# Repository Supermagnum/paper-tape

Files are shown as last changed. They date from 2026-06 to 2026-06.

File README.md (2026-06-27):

# Paper Tape Reader

**Repository:** [github.com/Supermagnum/paper-tape](https://github.com/Supermagnum/paper-tape)

<a href="https://www.pcbway.com/project/shareproject/paper_tape_reade_0e895082.html">PCB from PCBWay</a>

Design and documentation by [Jürgen Müller / e-basteln](https://e-basteln.de/computing/papertape/overview/). This repository contains the firmware, PCB design files, and manufacturing data for the manual optical paper tape reader described on the [e-basteln Paper Tape Reader pages](https://e-basteln.de/computing/papertape/overview/).

PCB files converted to KiCad. Note that the main board and included template PCBs use **1.6 mm** thickness. The Gerber files in `gerbers/papertape_spacer/` are for the **1.6 mm templates** (identifiable by their larger aperture holes), used as alignment guides during assembly.

The actual **spacers** (2× 1.2 mm thick) are **not included as Gerber files** and must be made separately. The main board and spacer templates also require **different PCB thicknesses** and must be ordered as **separate jobs** from your PCB manufacturer. Both 1.6 mm and 1.2 mm are standard thickness options at JLCPCB and PCBWay, with a minimum order of 5 pieces each.

The material of the spacers is not important, they just have to be light-tight. Options include 3D printing in black filament, or cutting from 1.2 mm black acrylic or similar opaque material. Use the 1.6 mm template PCB as a guide when making them. Make 2× spacers, for a total thickness of 2.4 mm.

## Table of Contents

- [Overview](#overview)
- [Using the Reader](#using-the-reader)
  - [Capturing tape data](#capturing-tape-data)
  - [After capture](#after-capture)
  - [Archiving captures on Codeberg](#archiving-captures-on-codeberg)
    - [Creating a Codeberg account](#creating-a-codeberg-account)
    - [Creating a repository](#creating-a-repository)
    - [Uploading files via the web interface](#uploading-files-via-the-web-interface)
- [LEDs](#leds)
- [Calibration](#calibration)
- [Jumpers](#jumpers)
- [Serial Output](#serial-output)
- [Building the Reader](#building-the-reader)
  - [Builder's Hints](#builders-hints)
    - [Sourcing the parts](#sourcing-the-parts)
    - [Preparing the PCBs](#preparing-the-pcbs)
    - [Populating components](#populating-components)
    - [Populating sockets and pins](#populating-sockets-and-pins)
    - [Programming the Pro Micro](#programming-the-pro-micro)
- [Design Approach](#design-approach)
- [The Sales Pitch](#the-sales-pitch)
- [Where to Find Files](#where-to-find-files)
- [Design Files](#design-files)
  - [Changes in this repository](#changes-in-this-repository)

## Overview

This little manual paper tape reader is easy to build and operate. It connects to any modern computer via USB, and performs well with all kinds of 5 to 8 bit paper tape, including translucent paper materials. To compensate for sensor tolerances and adjust to different paper types, it can automatically calibrate its optical sensors.

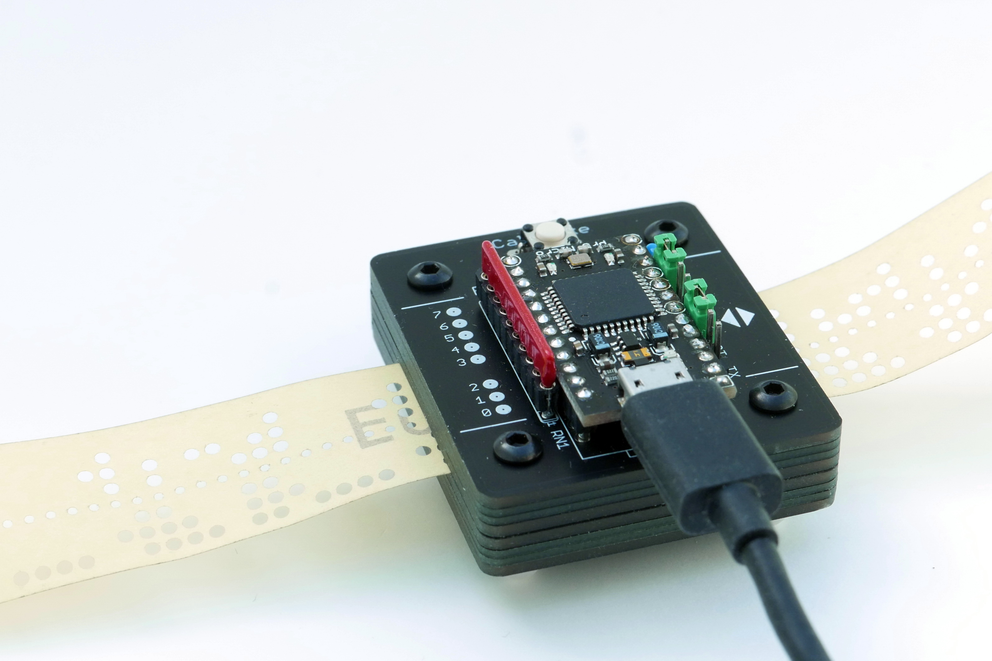
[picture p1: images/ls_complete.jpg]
Paper tape reader, fully assembled


The paper tape reader is controlled by an Arduino Pro Micro. Punched holes are detected optically, via analog inputs to the Arduino and automatic thresholding in software.

Optical readers for punched paper tape have been used since the 1940s; the one developed in 1942 for the British Heath Robinson deciphering machine was probably among the earliest. Non-motorized optical readers, where the tape is pulled through by hand, became popular with early computer amateurs in the 1970s. Oliver Audio Engineering launched the OP80A as a kit or complete unit in 1976; a replica is still commercially available today. And to this day, amateurs interested in the old paper tape format occasionally build their own optical readers.

Operate the reader handheld or mounted to a base plate. Tape is pulled through manually, at up to 1 meter/second feed rate.

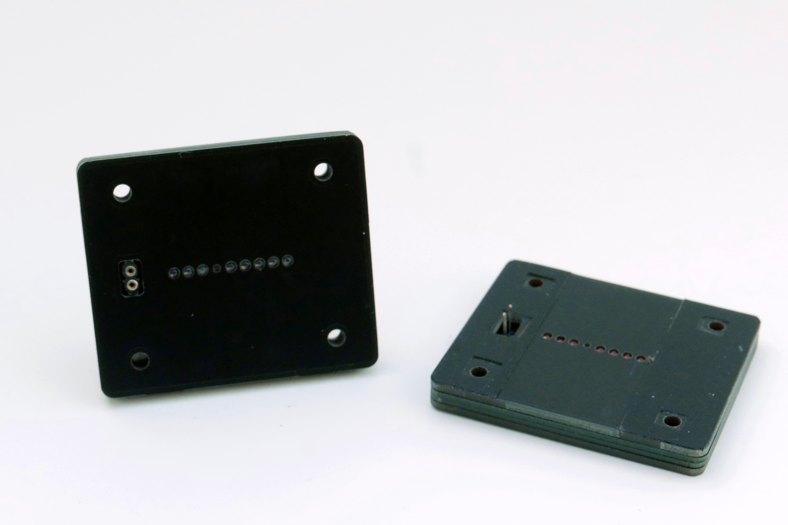
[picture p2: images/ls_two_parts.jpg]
Paper tape reader, illumination and detection module


The two main modules are the phototransistor detector (left) and the LED illuminator (right). The Arduino sits on top of the detector module. Only two power connections go to the illuminator.

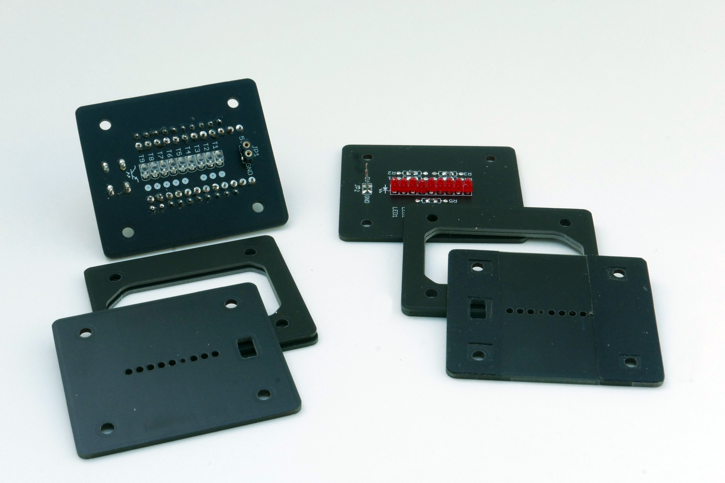
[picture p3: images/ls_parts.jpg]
Paper tape reader, individual parts


All chassis parts are made from PCB material: Circuit boards for phototransistors and LEDs, masks to precisely define the illumination and detection apertures, and light-tight spacers.

## Using the Reader

To use the paper tape reader, simply connect it to a Windows 10, Linux or Mac OS computer via USB. The reader should automatically register as a USB CDC device (communication device class, a virtual serial port).

Start a terminal program of your choice and select the right (virtual) serial port. No need to set the baud rate etc., since no physical serial port is involved. The reader will start sending data as soon as you pull paper tape through.

Before the first operation, or when switching to a new type of paper tape with very different transparency, calibrate the reader as described below.

### Capturing tape data

Open the serial port and save the received contents to a `.txt` file with **no processing**. Capture the raw bytes exactly as received, save as plain text, and do not strip or convert anything. This means:

- No parity bit masking
- No line ending conversion
- No stripping of leader/trailer nulls
- No interpretation of control characters

This preserves everything and keeps your options open for later analysis.

**Linux:** find the device (often `/dev/ttyACM0` or `/dev/ttyUSB0`), then capture directly:

```bash
stty -F /dev/ttyACM0 raw -echo
cat /dev/ttyACM0 > 20250627_tape_001.txt
```

Press Ctrl+C when the tape has passed through. Do not pipe through tools that alter line endings or encoding.

**macOS:** same approach using the device under `/dev/tty.usb*` or `/dev/cu.usb*`.

**Windows:** use a terminal that can log raw serial data to a file without translation (for example PuTTY with "All session output" logging, or a dedicated serial capture tool). Disable any "local echo", line editing, or automatic CR/LF conversion in the terminal settings.

A good naming convention helps since you do not know the content yet:

```
YYYYMMDD_tape_001.txt
```

If you are digitizing a collection, this lets you track what you have read and when, and rename files later once you figure out what each tape contains.

### After capture

Once you have a faithful raw capture, you can:

- Open it in a hex editor to inspect the raw bytes and identify the format
- Run `file tape_001.txt` on Linux, which will attempt to auto-detect the content type
- Look for recognizable patterns such as keywords (`PROGRAM`, `BEGIN`, `MOV`, `LDA`, etc.) that identify the language
- Check the [bitsavers.org](https://bitsavers.org/) archive, which has a large collection of documented paper tape formats for comparison

The key principle is: **capture first, identify later**. You can always convert a faithful raw capture, but you cannot recover data that was thrown away during capture.

### Archiving captures on Codeberg

If you want to share digitized tapes with the retrocomputing community, [Codeberg](https://codeberg.org/) is a good place to host them. Codeberg is independently operated by [Codeberg e.V.](https://codeberg.org/Codeberg/Association), a non-profit association registered in Berlin, Germany. It is community driven, privacy focused, and runs on the open-source [Forgejo](https://forgejo.org/) platform under German and EU law (GDPR). For archival work, that means no commercial pressure to monetize the platform, stronger data protection than many US-hosted services, and a community that tends to appreciate preservation projects.

#### Creating a Codeberg account

1. Open [codeberg.org](https://codeberg.org/) in your browser.
2. Click **Register** in the top-right corner.
3. Choose a username, enter your email address, and set a password.
4. Complete the registration form and submit it.
5. Check your email for a confirmation link from Codeberg and click it to activate the account.
6. Sign in with your new username and password.

#### Creating a repository

1. After signing in, click the **+** icon in the top-right corner and select **New Repository**.
   Alternatively, open your dashboard and click **New Repository** there.
2. Fill in the repository details:
   - **Owner:** your username (or an organization, if you belong to one)
   - **Repository name:** for example `paper-tape-archive`
   - **Description:** short summary, e.g. "Digitized paper tape captures"
   - **Visibility:** choose **Public** if you want others to browse and clone the archive
   - **Initialize repository:** leave **Add a README file** unchecked if you plan to upload your own files immediately; check it if you want Codeberg to create an empty starter `README.md` for you
3. Click **Create Repository**.

You now have an empty repository ready for uploads.

#### Uploading files via the web interface

Codeberg's web interface lets you add files without installing Git on your computer. This works well for small archives and individual tape captures.

**Upload the first files to an empty repository:**

1. Open your new repository in the browser.
2. If the repository is completely empty, Codeberg shows an **Upload file** option on the landing page. Click it.
   If the repository already has files, go to the **Code** tab, click the **+** drop-down next to the path bar, and choose **Upload file**.
3. Drag and drop files into the upload area, or click to browse your computer.
4. In the **Commit message** field, enter a short note such as `Add initial archive structure`.
5. Optionally expand **Commit options** and choose whether to commit directly to the default branch (usually `main`).
6. Click **Commit changes**.

**Add a tape capture in a subdirectory:**

1. Navigate to the folder where the tape should live, for example `tapes/unknown/20250627_tape_001/`.
   To create a new folder path, type the full path into the filename field when uploading, for example:
   `tapes/unknown/20250627_tape_001/tape_001.txt`
   Codeberg creates any missing directories automatically.
2. Upload the raw capture file (`tape_001.txt`) and the tape's `README.md` (create the README in the web editor if you prefer).
3. Enter a commit message such as `Add tape 001 capture from 2025-06-27`.
4. Click **Commit changes**.

**Create or edit a README in the browser:**

1. On the **Code** tab, click the **+** drop-down and choose **New file**.
2. Enter the path, for example `tapes/unknown/20250627_tape_001/README.md`.
3. Type or paste the README content into the editor.
4. Add a commit message and click **Commit changes**.

Repeat for each new tape. Once you have several captures, consider organizing them using the directory structure below.

Suggested directory structure:

```
paper-tape-archive/
├── README.md                    # Project description, how to contribute
├── FORMATS.md                   # Notes on identified tape formats
│
└── tapes/
    ├── unknown/                 # Tapes not yet identified
    │   └── 19700101_tape_001/
    │       ├── README.md        # Date, physical condition, likely source
    │       ├── tape_001.txt     # Raw capture
    │       └── tape_001.bin     # Raw binary if needed
    │
    ├── assembler/
    │   └── 19780315_tape_002/
    │       ├── README.md
    │       └── tape_002.txt
    │
    ├── basic/
    ├── fortran/
    ├── pascal/
    └── other/
```

Each tape's `README.md` should contain something like:

```markdown
# Tape 001

- **Date captured:** 2025-06-27
- **Capture device:** Paper Tape Reader (github.com/Supermagnum/paper-tape)
- **Likely source:** [e.g. university surplus, estate sale, donated collection]
- **Physical condition:** [good/fair/poor, any damage notes]
- **Tape width:** [5/7/8 bit]
- **Identified format:** unknown
- **Notes:** [anything else relevant]
```

Move tapes from `unknown/` into `assembler/`, `basic/`, `fortran/`, or another category once the format is identified, and update `FORMATS.md` with what you learned.

## LEDs

Two LEDs on the Pro Micro board are used to signal the operating status. They are labelled on the detector PCB:

- **FEED** flashes once for every valid feed hole detected during operation and calibration.
- **CAL** indicates that calibration mode is active, or that a calibration is recommended.

| CAL indication | Meaning |
|---|---|
| Steady ON | Calibration mode is active |
| Flashing, 1 Hz | Waiting for user to start calibration (press CAL button), or for 10 s timeout |
| Flashing, 10 Hz | Error during the calibration process |
| ON in read mode | Invalid brightness levels have been read (no clear high or low). Recalibration is recommended. |

## Calibration

1. Press **CAL** once to view the current calibration. Current calibration values are printed via USB, the CAL LED blinks at 1 Hz.
2. Press **CAL** again within 10 seconds to enter calibration mode. You will be prompted via a USB message to start feeding tape, the CAL LED turns on.
3. Feed tape, beginning within 10 seconds. Approximately 30 cm of sample tape are required. Ideally all data bits should be exercised in the sample, but if no significant contrast is detected for a data channel, averaged thresholds from the other channels will be used. The CAL LED stays on, the FEED LED begins to flash when valid feed holes are seen.
4. Calibration automatically ends when enough sample tape has been processed, or when one of the 10 second timeouts mentioned above is reached. Results and final status are printed via USB; errors are also signaled by rapid flashing of the CAL LED for 1 second. The CAL LED is then switched off.

## Jumpers

Three different tape widths can be set via jumpers. Setting them properly is recommended to avoid "CAL" indications from invalid detection levels at the tape edges, and to mask invalid bits from the output bytes.

| Tape width | Tape/bit placement | Jumper settings |
|---|---|---|
| 8 bit | 76543.210 | 5BIT=open, TST=open |
| 7 bit | - 6543.210 | 5BIT=set, TST=set |
| 5 bit | - - 432.10 - | 5BIT=set, TST=open |

Note that the 7-bit setting is only required for the rather uncommon type of paper tape which is physically only seven rows wide. For this narrower tape, the 7-bit setting masks out any invalid readings from the eighth detector (which looks just at the tape edge). The common 1" wide tape can be read in the 8-bit setting, no matter whether seven or eight rows of holes are actually punched on it.

Setting only the **TST** jumper will activate test mode, where the raw ADC readings from all 9 channels are printed on the output in an endless loop. From left to right, bits 0 to 7 are displayed, followed by the feedhole signal on the far right. A high value, up to 255, indicates high brightness.

The **INV** jumper will set the reader to use inverted intensity thresholds, i.e. a logical '1' or an active feed track pulse are signaled by a dark light level. This is useful for reading paper tapes which have not been punched, but printed on thin paper, for demonstrations or tests where real paper tape and a punch device are not available. Since the light levels will be lower in this case, it is recommended to replace the resistor array RN1 by a 22 kOhm array.

**TX** is not a jumper, but a serial output. This can optionally be used to connect legacy equipment. Please see the Serial Output section below for details.

## Serial Output

Normally, the USB port is used to interface the tape reader to a modern computer. If you want to read paper tapes into a vintage computer without a USB port, you can use the TX pin on the jumper row which sends "real" serial data.

- All data read from paper tape will be transmitted as an asynchronous serial data stream: 9600 baud, 8 data bits, no parity, 1 stop bit. Voltage levels are positive: A logical '1' (which is also present at rest) is represented by +5 V, a logical '0' (which is also the start bit of each character) by 0 V.
- The baud rate can only be changed by editing the Arduino source code. Look for the `SERIAL_INIT()` call; this is a macro which goes back to `Serial1.begin()` and accepts the baud rate as a parameter.
- To connect to computers with classic RS-232 ports, an external level converter to +/-5 V .. +/-12 V is needed. These are available off-the-shelf or as a kit. They also invert the signal polarity, making logical '1' a negative voltage as defined in the RS-232 standard.
- To provide 5 V power to the level converter, you can omit capacitor C1 and install two more posts (pins) in that position. The outermost pin has +5 V, the next one is another GND pin (see the pin table below). You can also power the paper tape reader via this pin if you do not want to use the USB port.
- Neither calibration data and prompts nor the raw ADC readings in TST mode will be transmitted via this output. This is deliberate; the idea is to use a modern PC to set up the reader, and not bother the vintage system with these setup data.

Summary of all pins on the jumper row and their functions:

| Pin | Function |
|-----|---|
| +5 V | Power, e.g. for optional external RS-232 level converter |
| GND | Ground (0 V) |
| 5BIT | Jumper to GND: 5 bit or 7 bit tape width |
| GND | Ground (0 V) |
| INV | Jumper to GND: Use printed paper tape with dark 'holes' |
| GND | Ground (0 V) |
| TST | Jumper to GND: Test mode, transmit raw ADC readings via USB |
| GND | Ground (0 V) |
| TX | Serial output: TTL level, 9600 8N1 |
| GND | Ground (0 V) |

## Building the Reader

There are no step-by-step illustrated building instructions here. But with the sectional view of the PCB stack below and the following hints the build should be straightforward.

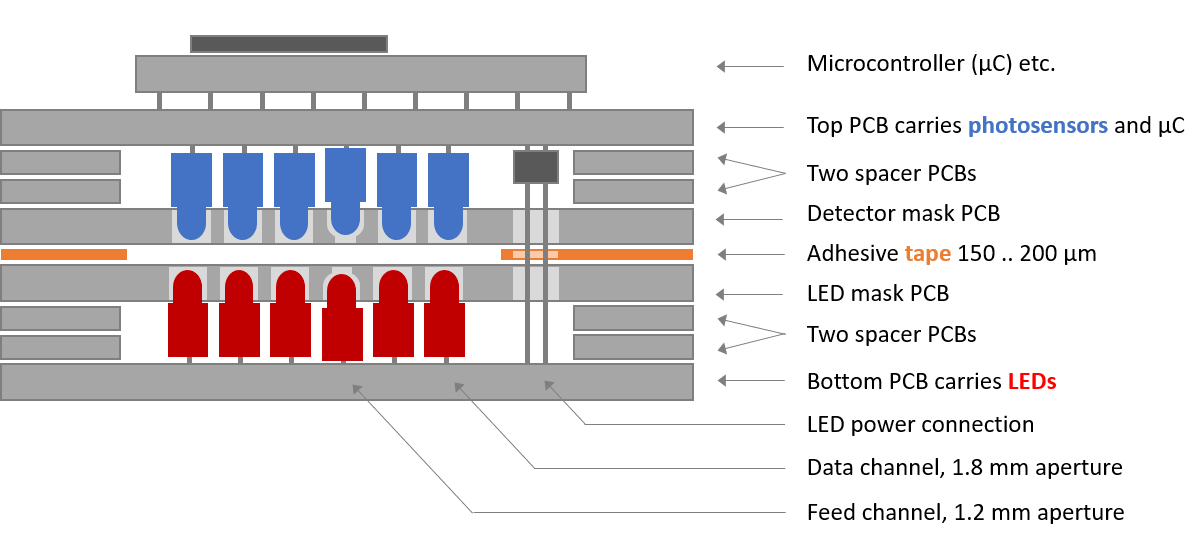
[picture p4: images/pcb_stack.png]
Sectional view of PCB stack and key components


Sectional view of the stack of PCBs which make the chassis, as well as the key electronic components. For clarity, only 5 of the 8 data sensors and LEDs are shown.

### Builder's Hints

#### Sourcing the parts

- The design files for the custom circuit boards are provided in the Design Files section below. You can order the PCBs cheaply from vendors like JLCPCB, PCBWay, Aisler etc. by uploading the zipped Gerber files provided.
- The [PCBWay shared project](https://www.pcbway.com/project/shareproject/paper_tape_reade_0e895082.html) lists all parts needed to build the reader (PCBs and components). The part list is in `docs/papertape_bom_PCBWay Community.csv`.
- While the microcontroller board is commonly called an "Arduino Pro Micro", and is fully compatible with the Arduino development tools, it was not designed by the Arduino company but by Sparkfun. You can purchase the original Sparkfun Pro Micro or one of various cheaper "Pro Micro" or "Arduino Pro Micro" clones available on ebay etc. In either case, be sure to buy the **5 V / 16 MHz** version! The variant operating at 3.3 V and 8 MHz is not suitable for this project.
- A Digikey shopping cart is available for most of the other parts. If you are based in Europe, Reichelt may be a lower-cost alternative supplier (see the bill of materials in the Design Files section below). The Digikey cart contains alternative values for the resistor array (2.7 kOhm or 10 kOhm), in case of major batch variations of the LEDs or photo-transistors. These may not be necessary. To my knowledge, all builds so far have successfully used the standard 4.7 kOhm array.

#### Preparing the PCBs

- The circuit boards and aperture boards for the detector and illumination are all made in one piece, to ensure that holes and milling contours align on all of them. (Probably an unnecessary precaution.) Hence you need to first break these boards apart, roughly clip off the tabs, and then sand the contours smooth. I recommend that you assemble the complete PCB package with screws according to the picture below and then sand it as a package to obtain even contours.
- Please note that the fibers in PCB dust may be harmful. Work outside or in an area where you can contain the dust, and wear a protective mask.

*The stack of PCBs that make the paper tape reader.*

- The aperture hole for the feed track is only 1.2 mm in diameter, matching the feed holes in the paper tape for maximum signal modulation. On both aperture PCBs this hole needs to be drilled out to 1.8 mm to accommodate the LED and phototransistor, as indicated in the silk screen print on the PCB. But do not drill all the way through; this must be drilled as a blind hole, preserving the 1.2 mm optical aperture! Note that extreme care must be exercised in drilling this hole. Use a drill press and/or much care to drill to the right depth. The standard tolerance for a 1.6 mm PCB is ±10%, which means ±0.16 mm. The WP406A10SURDK LED protrudes 1.55 mm up from its body; tolerance is ±0.25 mm, so start with a hole depth of 0.5 mm. Maximum you'd ever need to drill is 1.0 mm, leaving at worst 0.44 mm of wall.

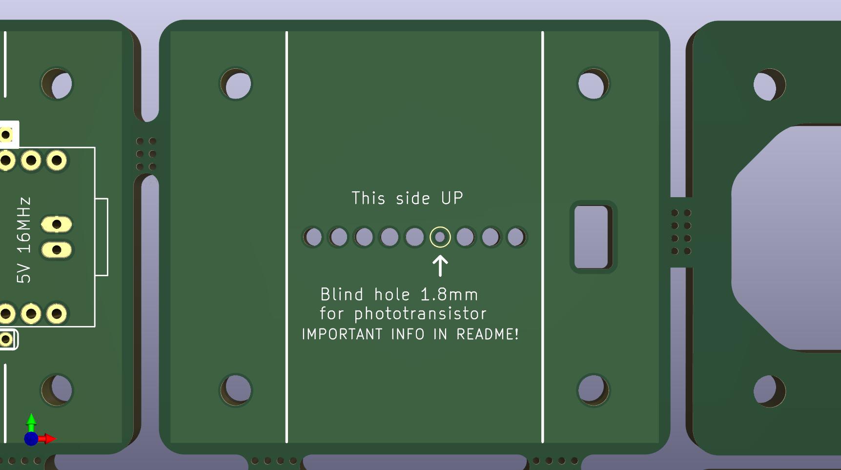
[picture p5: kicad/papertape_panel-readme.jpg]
Feed-track blind-hole drilling on aperture PCB


- To create a gap for the paper tape between the two aperture PCBs, two strips of adhesive tape are placed on top of the LED aperture board. This also provides lateral guidance for the paper tape, so you have to decide on a tape width you want to read. (I intend to provide inserts to reduce from 8-bit tape to 7 or 5 bit width, but have not tried this yet.)
- Fix the aperture PCB to the work bench with a bit of adhesive tape, position a short piece of punched paper tape exactly over the apertures as a reference and attach it to the bench as well. Apply two strips of adhesive tape to the PCB, right next to the paper tape, as a spacer and guide. About 200 um should be a good thickness; you may need to stack two layers of electrical tape or similar to get there. With a sharp knife, trim the tape along the PCB contours and cut the holes for screws and power connector.
- To make it easier to introduce the paper tape into the narrow gap later, you can lightly sand the edges of the LED aperture PCB in the space between the two guide tapes. This creates a slight "funnel" for insertion of the paper tape.

*The pre-assembled modules: Phototransistor detector with apertures (left) and LED illuminator with apertures and spacer tape (right). Two sockets and wires provide power to the LEDs.*

#### Populating components

- To populate the LEDs, insert all 9 loosely into the PCB. (Note the correct orientation; the body outline is shown on the silkscreen print.) Put the two spacer PCBs and the aperture PCB on top, wiggle the LEDs into their respective aperture holes, and hold the PCB stack together with screws or adhesive tape. Push the LEDs all the way down into their holes. The feed hole LED will not go quite as far into its blind hole as the other LEDs. Then solder all LEDs.
- Do the same with the phototransistors.
- The LED series resistors (R1 to R5) can be populated as through-hole resistors inside the module. This requires resistors with a diameter less than 2.4 mm, the thickness of the two spacer PCBs. The diameters of through-hole resistors vary by manufacturer. If you cannot find suitably slim through-hole resistors, you can either mount them on the opposite side of the PCB, or you can populate 0603 or 0805 sized SMD resistors on the provided pads.

#### Populating sockets and pins

- For the 5V power connection to the illuminator module, solder a two pin socket to the bottom of the detector board. (Make sure to get it reasonably straight.) Insert two clipped wire ends into the sockets. Provisionally assemble the full PCB stack while guiding the wires through their pads in the illuminator board. Clip wires to length and solder them to the illuminator board.
- You can solder the Arduino Pro Micro permanently to the detector PCB with the square soldering pins provided with most Arduino boards. This will give the lowest-profile package. If that is what you prefer, make sure that the phototransistors and 5V supply socket are soldered before you place the Arduino! Alternatively, use two rows of 1x12 pin sockets for the Arduino. In that case, the standard square pins will not fit, and you need to obtain smaller (turned) pin headers to match the sockets.
- The resistor array RN1 (9 x 4.7 kOhm) can be soldered directly if you only want to read "real", punched paper tape. Be sure to check the orientation; the common pin must be oriented towards the USB jack. If you want to use printed tape in the future, i.e. black dots on translucent paper, you may need to exchange RN1 for a 22 kOhm or 33 kOhm array to give higher light sensitivity. In that case, use a 1x10 pin socket for RN1.

*I opted for sockets for the resistor array (so I can try different values) and the Arduino (in case I need to get to the soldering joints beneath it).*

#### Programming the Pro Micro

- The Pro Micro processor is programmed via the regular Arduino environment, via its Micro USB connection. Please find the source code for the paper tape reader in the Design Files section just below.
- The Pro Micro board description is not pre-installed in the Arduino IDE. The required steps are briefly presented below. There is also a more detailed tutorial from Sparkfun; see the "Installing on Windows" or "Installing on Mac/Linux" sections there. That tutorial also covers manual installation of the serial driver on Windows if it is not available automatically (as it should from Windows 10 onwards).
- First, select **File / Preferences** from the main menu. In the dialog which opens, enter the URL below in the "Additional Board Manager URLs" field. Then select **Tools / Board / Boards Manager** and install the "SparkFun AVR Boards" package.

  ```
  https://raw.githubusercontent.com/sparkfun/Arduino_Boards/master/IDE_Board_Manager/package_sparkfun_index.json
  ```

- Again from the main menu, select **Tools / Processor: ATmega32U4 (5V, 16 MHz)**. It is important to choose the right version! If you accidentally try to program a 5V Pro Micro with the settings for the 3.3V version, you may brick it, requiring a hard reset. Connect the Pro Micro via USB, and set the right COM port via **Tools / Port**. Now you are ready to compile and upload the paper tape reader's software!

## Design Approach

This project takes a slightly different approach than most builds. While I also use LED and phototransistor pairs to detect the presence of holes or paper, and use the feed (sprocket) hole to trigger a read cycle, this reader does not distinguish "zero" from "one" via hardware comparators or Schmitt triggers. Instead, the on-board microcontroller (a Sparkfun/Arduino Pro Micro) reads the phototransistor currents via its analog inputs. This way it can adjust the detection thresholds in software, to compensate for tolerances between the phototransistors and to adjust to different paper materials.

## The Sales Pitch

- **Easy to use.** Just connect it to any modern computer (Windows 10, Mac OS, Linux) via USB, open a terminal program or copy from the serial device to a file, pull through some paper tape, and you are in business. You can calibrate the sensors to difficult-to-read, translucent tape by pushing a button and feeding about 30 cm of test tape. But one calibration handles a wide range of paper types, and stays resident in EEPROM memory, so you do not have to calibrate much at all.
- **Easy to build.** Only through-hole electronic components are required. Most mechanical parts consist of pre-fabricated circuit board material; just add four screws and some adhesive tape (which is used as a spacer to guide the paper tape). No hand-selected resistor values to get the sensor switching thresholds just right, since all sensors are calibrated in software. The microcontroller is programmed via USB and the standard Arduino environment.
- **Works pretty well.** Due to the analog sensing and software calibration, the reader handles a wide variety of tape materials robustly, including highly translucent white or yellow paper. It is insensitive to environmental light since the tape and sensors are fully encapsulated. While it is not the fastest reader around, reading speed is probably limited by how fast you can pull the tape through without damaging it: Reading at 1.2 meter/second (500 characters per second) should not be a problem.

## Where to Find Files

Clone or download this repository from [github.com/Supermagnum/paper-tape](https://github.com/Supermagnum/paper-tape).

```
paper-tape/
├── README.md                      # This manual
├── Paper_Tape_Reader.ino          # Arduino firmware
├── papertape_pcb.sch              # Original Eagle schematic
├── papertape_pcb.brd              # Original Eagle main PCB
├── papertape_spacer.brd           # Original Eagle spacer PCB
├── kicad/
│   ├── papertape_pcb.kicad_pcb    # Main PCB (KiCad, converted from Eagle)
│   ├── papertape_pcb.kicad_sch    # KiCad schematic
│   ├── papertape_pcb.kicad_pro    # KiCad project file
│   ├── papertape_spacer.kicad_pcb # Spacer PCB (KiCad)
│   └── papertape_panel.kicad_pcb  # Panel: main + 4x spacer (2x2, 2 mm gap)
├── gerbers/
│   ├── papertape_pcb/             # Gerbers for main board
│   ├── papertape_spacer/          # Gerbers for spacer board
│   └── papertape_panel/           # Gerbers for combined panel
├── docs/
│   ├── papertape_bom.pdf          # Bill of materials (original)
│   ├── papertape_bom.csv          # Bill of materials with manufacturer MPNs
│   ├── papertape_bom_PCBWay Community.csv  # Part list for PCBWay shared project
│   ├── papertape_all.pdf          # Full design documentation (PDF)
│   └── Paper_Tape_Template.xlsx   # Paper tape template
└── images/                        # Build photos and PCB stack diagram
    ├── ls_complete.jpg
    ├── ls_two_parts.jpg
    ├── ls_parts.jpg
    └── pcb_stack.png
```

Order PCBs and components from the [PCBWay shared project](https://www.pcbway.com/project/shareproject/paper_tape_reade_0e895082.html), which includes all parts needed; see `docs/papertape_bom_PCBWay Community.csv` for the part list. Alternatively, upload the Gerber files from `gerbers/papertape_pcb/` and `gerbers/papertape_spacer/`, or use `gerbers/papertape_panel/` for the combined panel layout. Both PCBWay and JLCPCB have a minimum order of 5 sets.

## Design Files

| File / directory | Description |
|---|---|
| `Paper_Tape_Reader.ino` | Arduino firmware source code |
| `kicad/papertape_pcb.kicad_pcb` | Main detector/illuminator PCB (KiCad) |
| `kicad/papertape_spacer.kicad_pcb` | Spacer PCB (KiCad) |
| `kicad/papertape_panel.kicad_pcb` | Combined panel: main board + 4x spacer (2x2 grid, 2 mm routing gap) |
| `kicad/papertape_pcb.kicad_sch` | KiCad schematic |
| `gerbers/papertape_pcb/` | Gerber + drill files for main board |
| `gerbers/papertape_spacer/` | Gerber + drill files for spacer |
| `gerbers/papertape_panel/` | Gerber + drill files for panel |
| `docs/papertape_bom.pdf` | Bill of materials (original PDF) |
| `docs/papertape_bom.csv` | Bill of materials with manufacturer part numbers (CSV) |
| `docs/papertape_bom_PCBWay Community.csv` | Part list for the PCBWay shared project (all parts needed) |
| `papertape_pcb.sch`, `papertape_pcb.brd` | Original Eagle design files |
| `papertape_spacer.brd` | Original Eagle spacer board |

### Changes in this repository

The original Eagle designs from [e-basteln](https://e-basteln.de/computing/papertape/overview/) have been converted to KiCad (`papertape_pcb.kicad_pcb`, `papertape_spacer.kicad_pcb`). During conversion, pre-drill holes were added to the PCB files where required for blind-milled feed-track apertures and other mechanical features that are not represented in the standard drill file alone.

For panelised manufacturing, the main PCB and spacer boards are also combined in `kicad/papertape_panel.kicad_pcb`: one main board at its original position, plus four spacer instances in a 2x2 grid to the right with a 2 mm routed gap between boards. Each panel is one complete set; PCBWay and JLCPCB both require a minimum order of 5 sets.

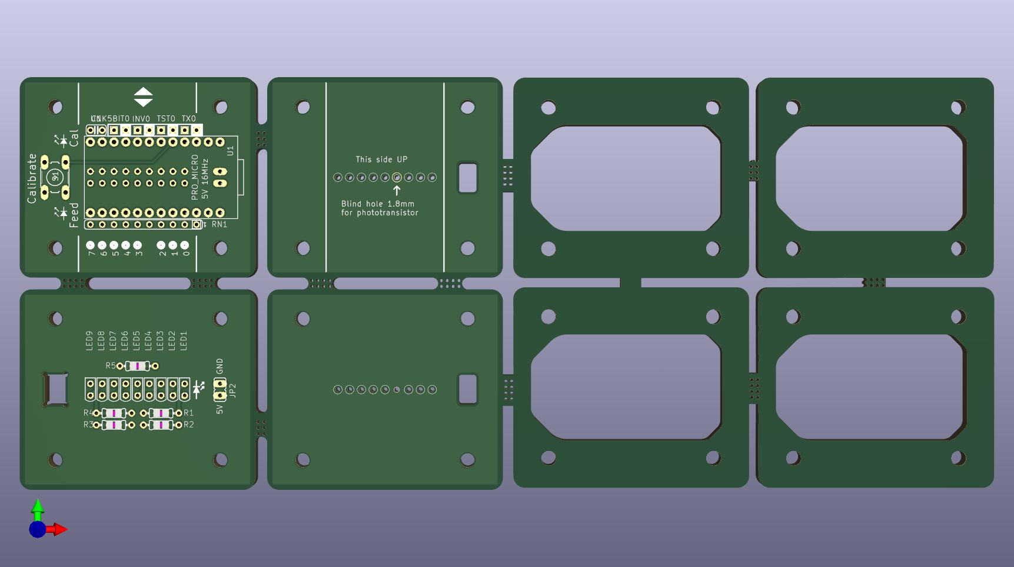
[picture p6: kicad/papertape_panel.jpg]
Paper tape PCB panel layout


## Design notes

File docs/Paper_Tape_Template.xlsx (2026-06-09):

"Punched" Paper Tape Template
jm 25.12.2020
Enter ASCII letters in green cells below
T | e | s | t |  | t | h | e |  | q | u | i | c | k |  | b | r | o | w | n |  | f | o | x |  | j | u | m | p | e | d |  | o | v | e | r |  | t | h | e |  | l | a | z | y |  | d | o | g | . |  | T | E | S | T |  | T | H
l | l | l | l |  | l | l | l |  | l | l | l | l | l |  | l | l | l | l | l |  | l | l | l |  | l | l | l | l | l | l |  | l | l | l | l |  | l | l | l |  | l | l | l | l |  | l | l | l |  |  | l | l | l | l |  | l | l
 | l | l | l | l | l | l | l | l | l | l | l | l | l | l | l | l | l | l | l | l | l | l | l | l | l | l | l | l | l | l | l | l | l | l | l | l | l | l | l | l | l | l | l | l | l | l | l | l | l |  |  |  |  |  | l
l |  | l | l |  | l |  |  |  | l | l |  |  |  |  |  | l |  | l |  |  |  |  | l |  |  | l |  | l |  |  |  |  | l |  | l |  | l |  |  |  |  |  | l | l |  |  |  |  |  |  | l |  | l | l |  | l
 |  |  |  |  |  | l |  |  |  |  | l |  | l |  |  |  | l |  | l |  |  | l | l |  | l |  | l |  |  |  |  | l |  |  |  |  |  | l |  |  | l |  | l | l |  |  | l |  | l |  |  |  |  |  |  |  | l
l | l | l | l | l | l | l | l | l | l | l | l | l | l | l | l | l | l | l | l | l | l | l | l | l | l | l | l | l | l | l | l | l | l | l | l | l | l | l | l | l | l | l | l | l | l | l | l | l | l | l | l | l | l | l | l | l | l
l | l |  | l |  | l |  | l |  |  | l |  |  |  |  |  |  | l | l | l |  | l | l |  |  |  | l | l |  | l | l |  | l | l | l |  |  | l |  | l |  | l |  |  |  |  | l | l | l | l |  | l | l |  | l |  | l
 |  | l |  |  |  |  |  |  |  |  |  | l | l |  | l | l | l | l | l |  | l | l |  |  | l |  |  |  |  |  |  | l | l |  | l |  |  |  |  |  |  |  | l |  |  |  | l | l | l |  |  |  | l
 | l | l |  |  |  |  | l |  | l | l | l | l | l |  |  |  | l | l |  |  |  | l |  |  |  | l | l |  | l |  |  | l |  | l |  |  |  |  | l |  |  | l |  | l |  |  | l | l |  |  |  | l | l
Enter ASCII letters in green cells below
l | l | l | l | l | l | l | l | l | l | l | l | l | l | l | l | l | l | l | l | l | l | l | l | l | l | l | l | l | l | l | l | l | l | l | l | l | l | l | l | l | l | l | l | l | l | l | l | l | l | l | l | l | l | l | l | l | l
Enter ASCII letters in green cells below
l | l | l | l | l | l | l | l | l | l | l | l | l | l | l | l | l | l | l | l | l | l | l | l | l | l | l | l | l | l | l | l | l | l | l | l | l | l | l | l | l | l | l | l | l | l | l | l | l | l | l | l | l | l | l | l | l | l
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

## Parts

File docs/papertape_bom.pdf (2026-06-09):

Paper tape reader - bill of materials
jm 23.12.2020
Ref | Count Value | Reichelt Nr. | Euro
| | | /unit | Euro
| | | | total | Comments
R1 - R4 | 4 1 kOhm, Yageo | METALL 1,00K (https://www.reichelt.de/widerstand-metallschicht-1-00-kohm-0207-0-6-w-1--metall-1-00k-p11403.html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) | 0,08 | 0,32 | diameter < 2.4 mm! Alternatively use 0603 or 0805 SMD type.
R5 | 1 680 Ohm, Yageo | METALL 680 (https://www.reichelt.de/widerstand-metallschicht-680-ohm-0207-0-6-w-1--metall-680-p11942.html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) | 0,08 | 0,08
RN1 | 1 9*4,7k | SIL 10-9 4,7K (https://www.reichelt.de/widerstandsnetzwerk-4-7-kohm-sternschaltung-9wid-10pins-sil-10-9-4-7k-p17650.html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) | 0,10 | 0,10
C1 | 1 100 nF, RM 2.54 mm | X7R-2,5 100N (https://www.reichelt.de/vielschicht-keramikkondensator-100n-10--x7r-2-5-100n-p22853.html?trstct=pol_2&nbc=1) | 0,07 | 0,07
LED1 - LED9 | 9 Kingbright L-2060SRD | LED 1,8MM SRT (https://www.reichelt.de/mini-led-1-8-mm-bedrahtet-rot-200-mcd-70--led-1-8mm-srt-p31601.html?trstct=pos_0&nbc=1) | 0,13 | 1,17
T1 - T9 | 9 Vishay BPW 17N | BPW 17N (https://www.reichelt.de/fototransistor-npn-450-1040nm-24-tht-1-8mm-bpw-17n-p5800.html?trstct=pos_0&nbc=1) | 0,37 | 3,33
S1 | 1 OMRON B3F-1002 | OMR B3F-1002 (https://www.reichelt.de/kurzhubtaster-b3f-serie-1-no-24-v-dc-50-ma-omr-b3f-1002-p258312.html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) | 0,31 | 0,31
JP1 | 1 Precision socket 1*2 | MPE 006-1-002 (https://www.reichelt.de/praezision-sockelstreifen-rm-2-54-2-pol--mpe-006-1-002-p187285.html?trstct=pol_0&nbc=1) | 0,12 | 0,12 | or use part of Arduino/RN1 socket below
JP2 | 1 two wire ends | n/a | | | use clipped wire ends
U1 | 1 "Arduino" Pro Micro 16 MHz 5V | n/a | | | original from Sparkfun or generic from ebay
Jumper | 1 Pin header 1*8 pins | MPE 087-1-008 (https://www.reichelt.de/stiftleisten-2-54-mm-1x08-gerade-mpe-087-1-008-p119884.html?trstct=pol_0&nbc=1) | 0,19 | 0,19 | optional: For TX, TST, INV, 5BIT jumpers
Arduino socket | 2 Precision socket 1*20 | SPL 20 (https://www.reichelt.de/buchsenleiste-20-polig-einreihig-rm-2-54-gerade-spl-20-p19398.html?trstct=pol_2&nbc=1) | 0,36 | 0,72 | optional, to keep Arduino removable. Need 2*12 pins; can use rest for RN1, JP1.
Arduino pins | 2 Precision pins 1*20 | AW 122/20 (https://www.reichelt.de/ic-adapterleiste-20-polig-einreihig-rm-2-54-aw-122-20-p4426.html?trstct=pol_6&nbc=1) | 0,74 | 1,48 | optional, when using socket. Need 2*12 pins. Can use bare wires to reduce height.
Screws | 4 M3 * 12 mm | | | | slightly longer than 12 mm preferred
Nuts | 4 M3 | | | | use hat nut or knurled nut to serve as feet for the reader
Total | | | | 7,88

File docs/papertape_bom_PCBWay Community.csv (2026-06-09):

Reference | Qty | Value | Manufacturer | MPN | Description | Notes
R1 | 1 | 1 kOhm | Yageo | CFR-25JB-52-1K | Resistor 1/4W 5% 1 kOhm axial | Body diameter < 2.4 mm; or 0805 SMD equivalent on R1A pad
R2 | 1 | 1 kOhm | Yageo | CFR-25JB-52-1K | Resistor 1/4W 5% 1 kOhm axial | Body diameter < 2.4 mm; or 0805 SMD equivalent on R2A pad
R3 | 1 | 1 kOhm | Yageo | CFR-25JB-52-1K | Resistor 1/4W 5% 1 kOhm axial | Body diameter < 2.4 mm; or 0805 SMD equivalent on R3A pad
R4 | 1 | 1 kOhm | Yageo | CFR-25JB-52-1K | Resistor 1/4W 5% 1 kOhm axial | Body diameter < 2.4 mm; or 0805 SMD equivalent on R4A pad
R5 | 1 | 680 Ohm | Yageo | CFR-25JB-52-680R | Resistor 1/4W 5% 680 Ohm axial | Body diameter < 2.4 mm; or 0805 SMD equivalent on R5A pad
RN1 | 1 | 9 x 4.7 kOhm | Vishay | CSC09A014K70GEK | Resistor network 9-pin SIL bussed 4.7 kOhm 2% | Alternative: FREI L 10-1S 2% 4.7 K; alt values 2.7k/10k for LED/PT batch variation; 22k/33k for printed-tape (INV jumper)
C1 | 1 | 100 nF | Kemet | C315C104M1U5TA | Capacitor ceramic 100 nF 50 V radial 2.54 mm pitch | Reichelt equivalent: X7R-2.5 100N
LED1 | 1 |  | Kingbright | L-2060SRD | LED 1.8 mm red THT | Feed/data channel LED
LED2 | 1 |  | Kingbright | L-2060SRD | LED 1.8 mm red THT | Feed/data channel LED
LED3 | 1 |  | Kingbright | L-2060SRD | LED 1.8 mm red THT | Feed/data channel LED
LED4 | 1 |  | Kingbright | L-2060SRD | LED 1.8 mm red THT | Feed/data channel LED
LED5 | 1 |  | Kingbright | L-2060SRD | LED 1.8 mm red THT | Feed/data channel LED
LED6 | 1 |  | Kingbright | L-2060SRD | LED 1.8 mm red THT | Feed/data channel LED
LED7 | 1 |  | Kingbright | L-2060SRD | LED 1.8 mm red THT | Feed/data channel LED
LED8 | 1 |  | Kingbright | L-2060SRD | LED 1.8 mm red THT | Feed/data channel LED
LED9 | 1 |  | Kingbright | L-2060SRD | LED 1.8 mm red THT | Feed/data channel LED
T1 | 1 |  | Vishay | BPW17N | Phototransistor NPN T-3/4 | Data/feed sensor
T2 | 1 |  | Vishay | BPW17N | Phototransistor NPN T-3/4 | Data/feed sensor
T3 | 1 |  | Vishay | BPW17N | Phototransistor NPN T-3/4 | Data/feed sensor
T4 | 1 |  | Vishay | BPW17N | Phototransistor NPN T-3/4 | Data/feed sensor
T5 | 1 |  | Vishay | BPW17N | Phototransistor NPN T-3/4 | Data/feed sensor
T6 | 1 |  | Vishay | BPW17N | Phototransistor NPN T-3/4 | Data/feed sensor
T7 | 1 |  | Vishay | BPW17N | Phototransistor NPN T-3/4 | Data/feed sensor
T8 | 1 |  | Vishay | BPW17N | Phototransistor NPN T-3/4 | Data/feed sensor
T9 | 1 |  | Vishay | BPW17N | Phototransistor NPN T-3/4 | Data/feed sensor
S1 | 1 |  | Omron | B3F-1002 | Tactile switch 6x6 mm 0.9 mm plunger yellow | CAL button
JP1 | 1 | 1x2 socket | Binder MPE GmbH | 006-1-002-D-B1STF-XS0 | Precision socket strip 1x2 2.54 mm pitch | 5 V power link to illuminator; or share pins from Arduino/RN1 socket
JP2 | 1 | Wire jumper |  |  | Two clipped wire ends | 5 V power link to illuminator module
U1 | 1 | Pro Micro 5V 16 MHz | SparkFun | DEV-12640 | Arduino-compatible ATmega32U4 board | 5 V / 16 MHz only; generic clones also work
J1 | 1 | 1x8 header | Binder MPE GmbH | 087-1-008-0-S-XS0-1260 | Pin header strip 1x8 2.54 mm pitch straight | Optional jumpers for TX TST INV 5BIT
J2 | 1 | 1x20 socket | FREI | SPL 20 | Precision socket strip 1x20 2.54 mm pitch straight | Optional Arduino socket (need 2x12 positions)
J3 | 1 | 1x20 socket | FREI | SPL 20 | Precision socket strip 1x20 2.54 mm pitch straight | Optional Arduino socket (need 2x12 positions)
J4 | 1 | 1x20 pin header | ASSMANN WSW | AW 122-20/G-T | Precision pin header strip 1x20 2.54 mm pitch straight | Optional mating pins for Arduino socket (need 2x12 positions)
J5 | 1 | 1x20 pin header | ASSMANN WSW | AW 122-20/G-T | Precision pin header strip 1x20 2.54 mm pitch straight | Optional mating pins for Arduino socket (need 2x12 positions)
HW1 | 4 | M3 x 12 mm |  | DIN 912 M3x12 | Socket head cap screw M3 12 mm | Slightly longer than 12 mm acceptable
HW2 | 4 | M3 |  | DIN 934 M3 | Hex nut M3 | Knurled or cap nut recommended as feet

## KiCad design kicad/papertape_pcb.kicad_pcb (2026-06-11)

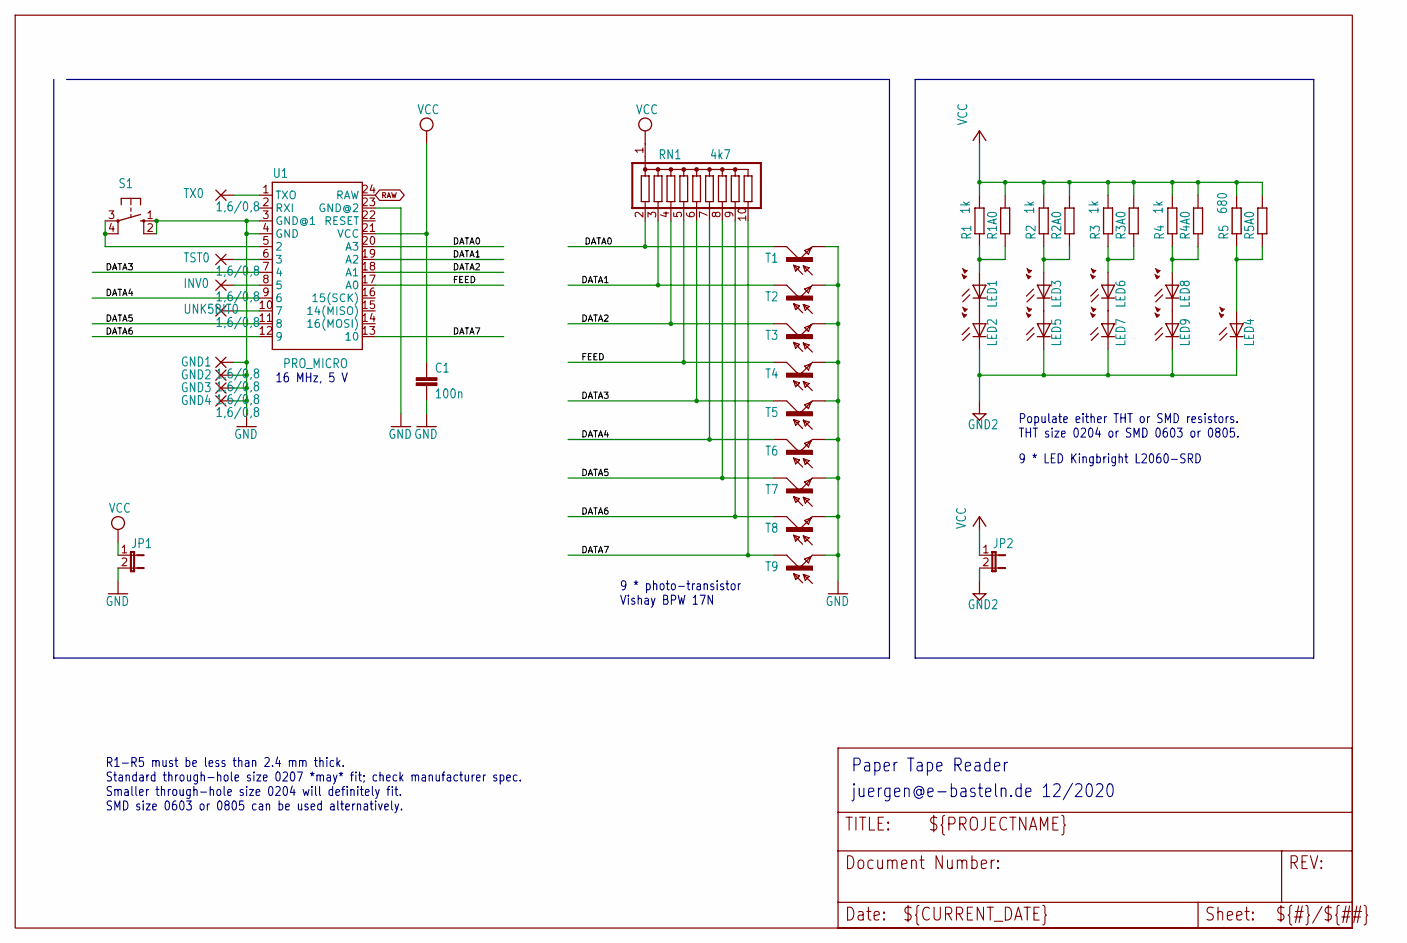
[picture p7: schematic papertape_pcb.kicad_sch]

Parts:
C1: 100n; C025-024X044
GND1, GND2, GND3, GND4: 1,6/0,8; 1,6_0,8
INV0: 1,6/0,8; 1,6_0,8
JP1, JP2: JP1E; JP1
LED1, LED2, LED3, LED4, LED5, LED6, LED7, LED8, LED9: LEDLED1MM8; LED1MM8
R1, R2, R3, R4: 1k; 0204_7
R1A0, R2A0, R3A0, R4A0, R5A0: R-EU_R0805; R0805
R5: 680; 0204_7
RN1: 4k7; SIL10
S1: 10-XX; B3F-10XX
T1, T2, T3, T4, T5, T6, T7, T8, T9: BPW17N
TST0: 1,6/0,8; 1,6_0,8
TX0: 1,6/0,8; 1,6_0,8
U1: PRO_MICRO; SPARKFUN_PRO_MICRO
UNK5BIT0: 1,6/0,8; 1,6_0,8

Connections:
DATA0: RN1.2, T1.C, U1.20 (A3)
DATA1: RN1.3, T2.C, U1.19 (A2)
DATA2: RN1.4, T3.C, U1.18 (A1)
DATA3: RN1.6, T5.C, U1.7 (4)
DATA4: RN1.7, T6.C, U1.9 (6)
DATA5: RN1.8, T7.C, U1.11 (8)
DATA6: RN1.9, T8.C, U1.12 (9)
DATA7: RN1.10, T9.C, U1.13 (10)
FEED: RN1.5, T4.C, U1.17 (A0)
GND: C1.2, GND1.1, GND2.1, GND3.1, GND4.1, JP1.2, S1.1 (S), S1.2 (S1), T1.E, T2.E, T3.E, T4.E, T5.E, T6.E, T7.E, T8.E, T9.E, U1.3 (GND@1), U1.4 (GND), U1.23 (GND@2)
GND2: JP2.2, LED2.K (C), LED4.K (C), LED5.K (C), LED7.K (C), LED9.K (C)
unnamed: LED1.K (C), LED2.A
unnamed: LED3.K (C), LED5.A
unnamed: LED6.K (C), LED7.A
unnamed: LED8.K (C), LED9.A
unnamed: INV0.1, U1.8 (5)
unnamed: TST0.1, U1.6 (3)
unnamed: LED4.A, R5.1, R5A0.1
unnamed: TX0.1, U1.1 (TXO)
unnamed: U1.10 (7), UNK5BIT0.1
unnamed: S1.3, S1.4 (P1), U1.5 (2)
unnamed: LED1.A, R1.1, R1A0.1
unnamed: LED3.A, R2.1, R2A0.1
unnamed: LED6.A, R3.1, R3A0.1
unnamed: LED8.A, R4.1, R4A0.1
RAW: U1.24 (RAW)

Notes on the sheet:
juergen@e-basteln.de 12/2020
9 * photo-transistor Vishay BPW 17N
9 * LED Kingbright L2060-SRD
16 MHz, 5 V
Paper Tape Reader
Populate either THT or SMD resistors. THT size 0204 or SMD 0603 or 0805.
R1-R5 must be less than 2.4 mm thick. Standard through-hole size 0207 *may* fit; check manufacturer spec. Smaller through-hole size 0204 will definitely fit. SMD size 0603 or 0805 can be used alternatively.

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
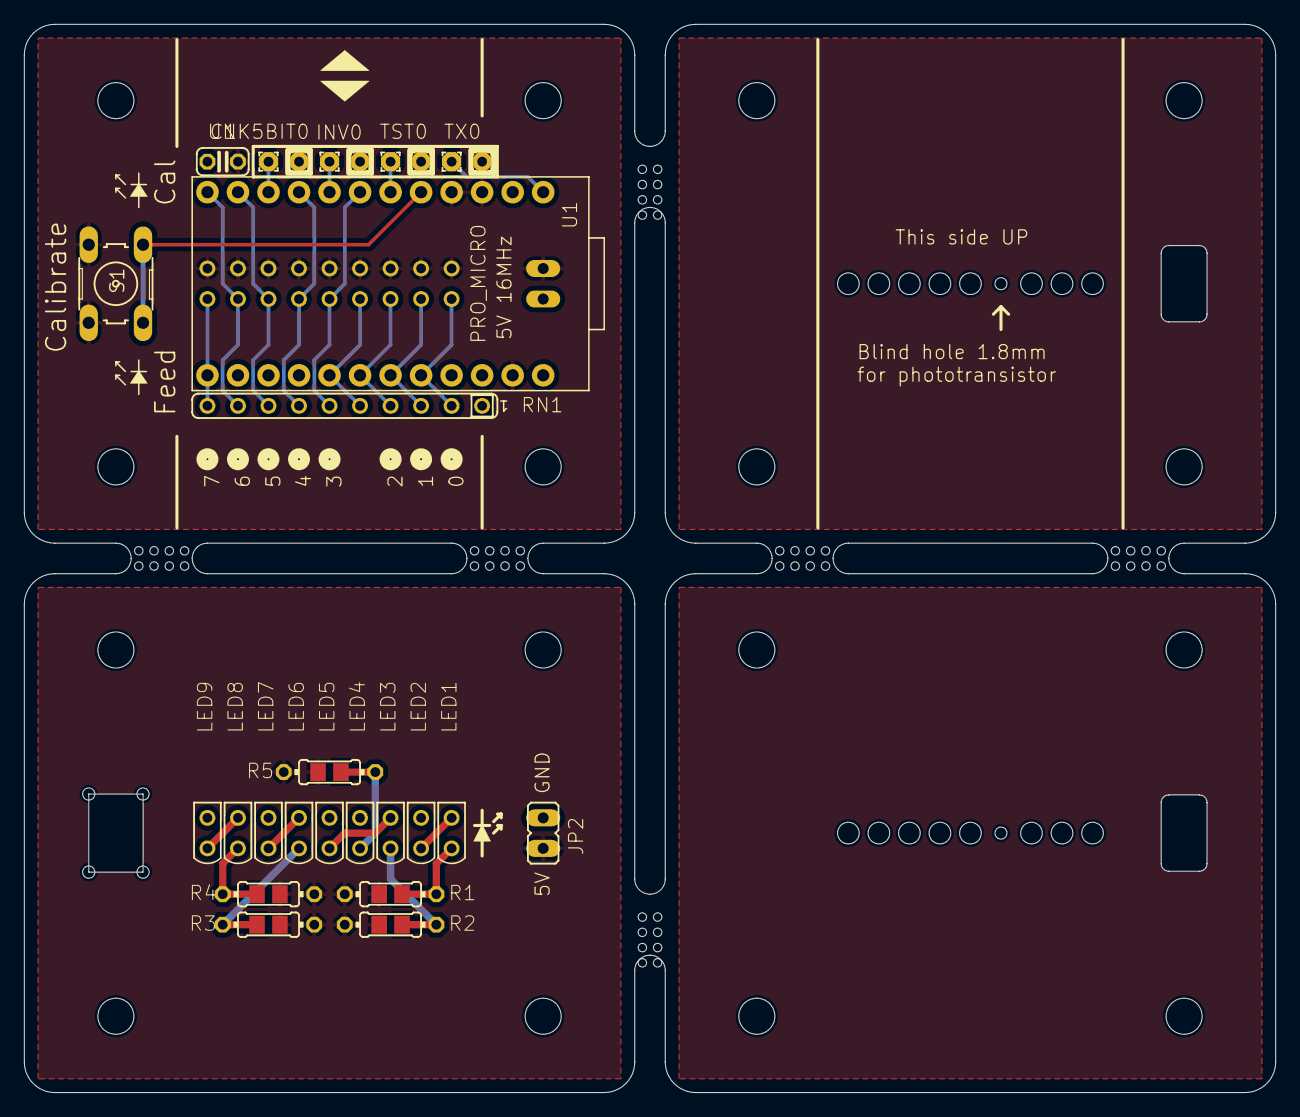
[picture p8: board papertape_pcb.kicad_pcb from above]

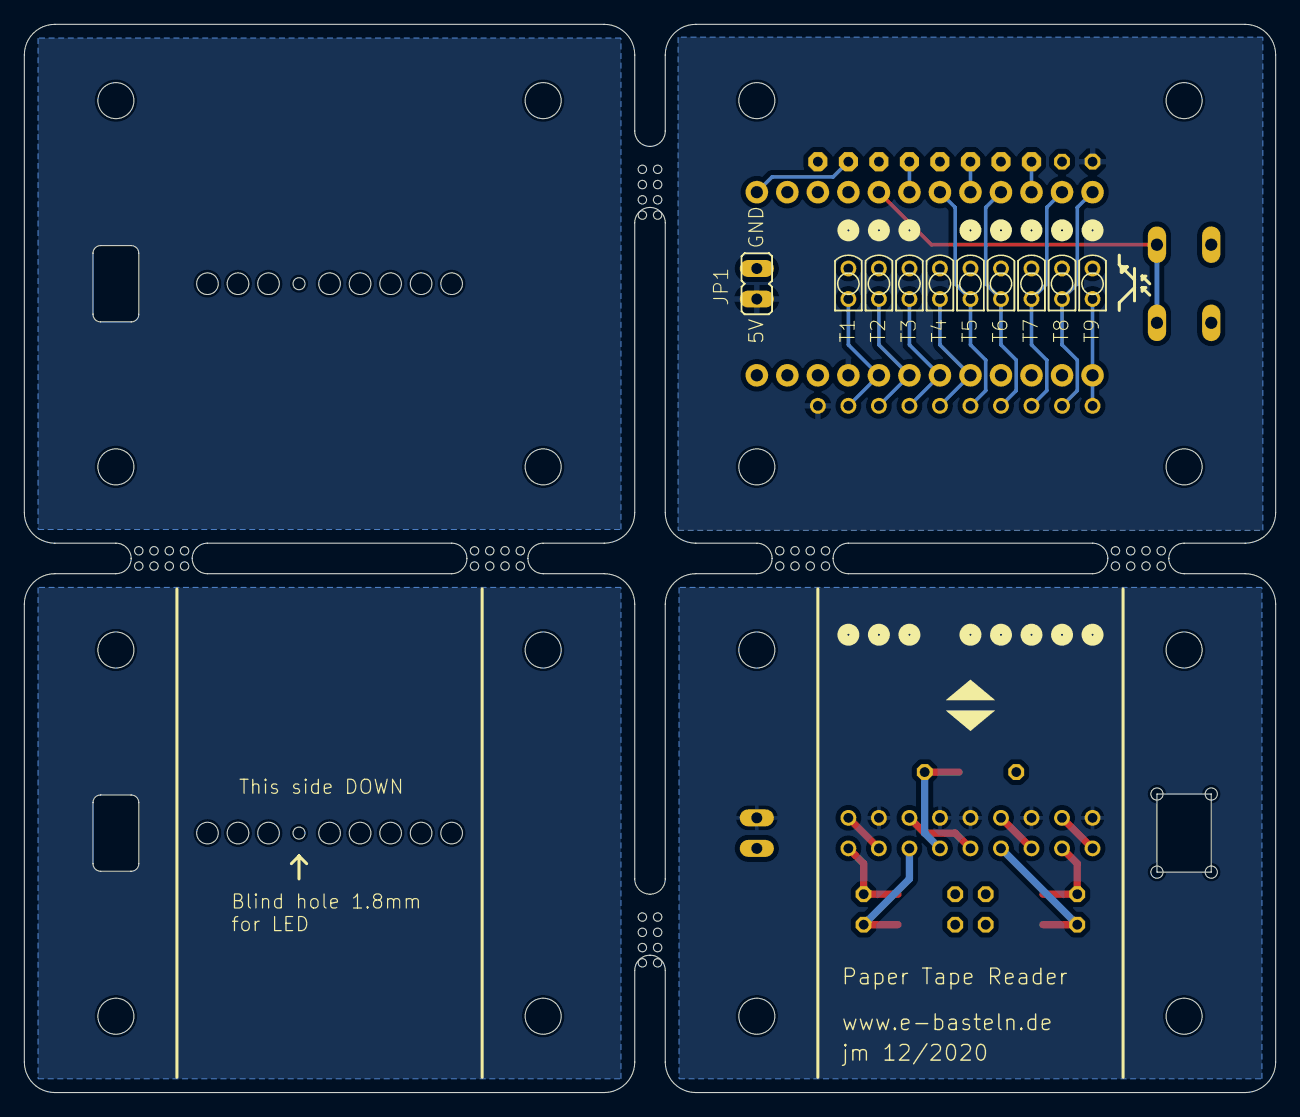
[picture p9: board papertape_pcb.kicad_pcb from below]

Board: 2 copper layers, 104.1 x 88.9 mm, 128 parts (10 on the bottom side), 27 nets.

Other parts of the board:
UNK_HOLE_0: dummyfp0
UNK_HOLE_1: dummyfp1
UNK_HOLE_2: dummyfp2
UNK_HOLE_3: dummyfp3
UNK_HOLE_4: dummyfp4
UNK_HOLE_5: dummyfp5
UNK_HOLE_6: dummyfp6
UNK_HOLE_7: dummyfp7
UNK_HOLE_8: dummyfp8
UNK_HOLE_9: dummyfp9
UNK_HOLE_10: dummyfp10
UNK_HOLE_11: dummyfp11
UNK_HOLE_12: dummyfp12
UNK_HOLE_13: dummyfp13
UNK_HOLE_14: dummyfp14
UNK_HOLE_15: dummyfp15
UNK_HOLE_16: dummyfp16
UNK_HOLE_17: dummyfp17
UNK_HOLE_18: dummyfp18
UNK_HOLE_19: dummyfp19
UNK_HOLE_20: dummyfp20
UNK_HOLE_21: dummyfp21
UNK_HOLE_22: dummyfp22
UNK_HOLE_23: dummyfp23
UNK_HOLE_24: dummyfp24
UNK_HOLE_25: dummyfp25
UNK_HOLE_26: dummyfp26
UNK_HOLE_27: dummyfp27
UNK_HOLE_28: dummyfp28
UNK_HOLE_29: dummyfp29
UNK_HOLE_30: dummyfp30
UNK_HOLE_31: dummyfp31
UNK_HOLE_32: dummyfp32
UNK_HOLE_33: dummyfp33
UNK_HOLE_34: dummyfp34
UNK_HOLE_35: dummyfp35
UNK_HOLE_36: dummyfp36
UNK_HOLE_37: dummyfp37
UNK_HOLE_38: dummyfp38
UNK_HOLE_39: dummyfp39
UNK_HOLE_40: dummyfp40
UNK_HOLE_41: dummyfp41
UNK_HOLE_42: dummyfp42
UNK_HOLE_43: dummyfp43
UNK_HOLE_44: dummyfp44
UNK_HOLE_45: dummyfp45
UNK_HOLE_46: dummyfp46
UNK_HOLE_47: dummyfp47
UNK_HOLE_48: dummyfp48
UNK_HOLE_49: dummyfp49
UNK_HOLE_50: dummyfp50
UNK_HOLE_51: dummyfp51
UNK_HOLE_52: dummyfp52
UNK_HOLE_53: dummyfp53
UNK_HOLE_54: dummyfp54
UNK_HOLE_55: dummyfp55
UNK_HOLE_56: dummyfp56
UNK_HOLE_57: dummyfp57
UNK_HOLE_58: dummyfp58
UNK_HOLE_59: dummyfp59
UNK_HOLE_60: dummyfp60
UNK_HOLE_61: dummyfp61
UNK_HOLE_62: dummyfp62
UNK_HOLE_63: dummyfp63
UNK_HOLE_64, UNK_HOLE_65, UNK_HOLE_66, UNK_HOLE_67: dummyfp_cutout
UNK_HOLE_68: dummyfp_predrill1
UNK_HOLE_69: dummyfp_predrill2
UNK_HOLE_70: dummyfp_predrill3
UNK_HOLE_71: dummyfp_predrill4
UNK_HOLE_72: dummyfp_predrill5
UNK_HOLE_73: dummyfp_predrill6
UNK_HOLE_74: dummyfp_predrill7
UNK_HOLE_75: dummyfp_predrill8
UNK_HOLE_76: dummyfp_predrill9
UNK_HOLE_77: dummyfp_predrill10
UNK_HOLE_78: dummyfp_predrill11
UNK_HOLE_79: dummyfp_predrill12
UNK_HOLE_80: dummyfp_predrill13
UNK_HOLE_81: dummyfp_predrill14
UNK_HOLE_82: dummyfp_predrill15
UNK_HOLE_83: dummyfp_predrill16
UNK_HOLE_84: dummyfp_predrill17
UNK_HOLE_85: dummyfp_predrill18

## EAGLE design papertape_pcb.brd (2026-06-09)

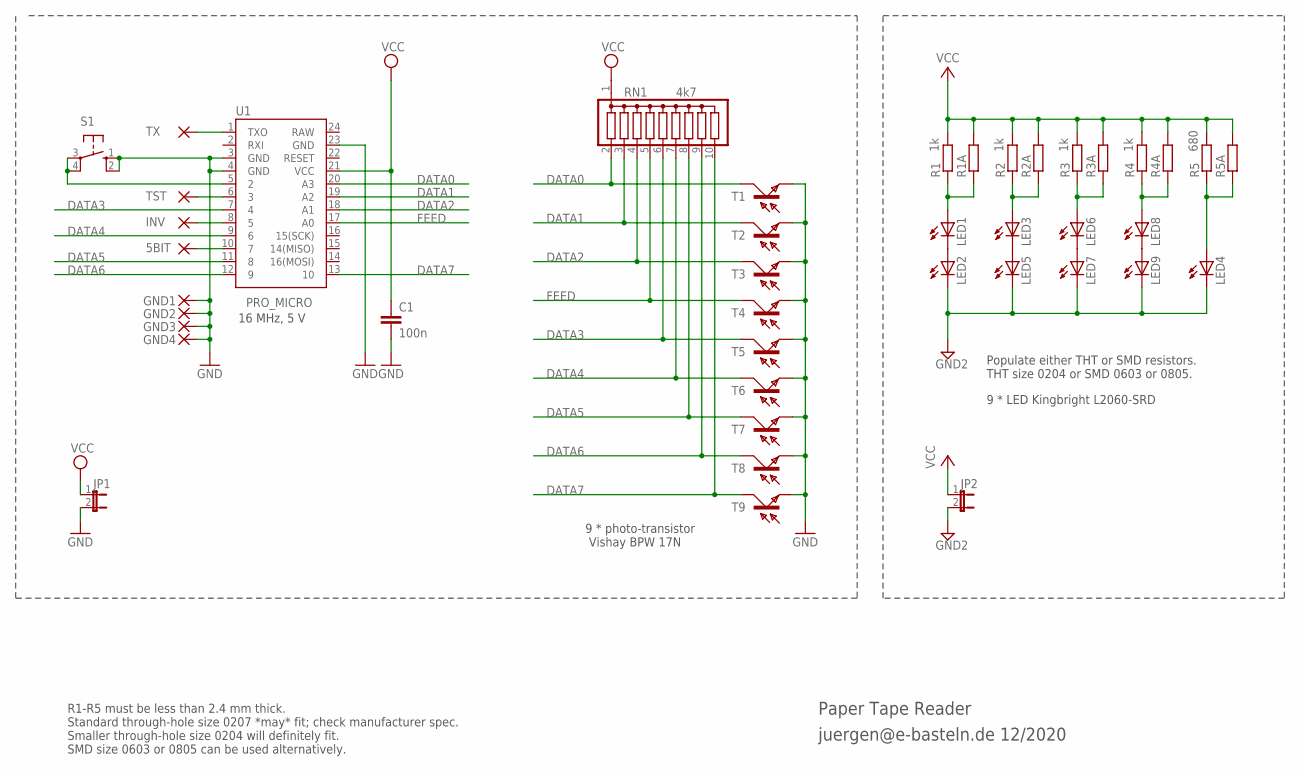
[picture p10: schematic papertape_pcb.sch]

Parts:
5BIT: 1,6/0,8
C1: 100n; C025-024X044
GND1, GND2, GND3, GND4: 1,6/0,8
INV: 1,6/0,8
JP1, JP2: JP1E; JP1
LED1, LED2, LED3, LED4, LED5, LED6, LED7, LED8, LED9: LEDLED1MM8; LED1MM8
R1, R2, R3, R4: 1k; 0204/7
R1A, R2A, R3A, R4A, R5A: R-EU_R0805; R0805
R5: 680; 0204/7
RN1: 4k7; SIL10
S1: 10-XX; B3F-10XX
T1, T2, T3, T4, T5, T6, T7, T8, T9: BPW17N
TST: 1,6/0,8
TX: 1,6/0,8
U1: PRO_MICRO; SPARKFUN_PRO_MICRO

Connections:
DATA0: RN1.2, T1.C, U1.20 (A3)
DATA1: RN1.3, T2.C, U1.19 (A2)
DATA2: RN1.4, T3.C, U1.18 (A1)
DATA3: RN1.6, T5.C, U1.7 (4)
DATA4: RN1.7, T6.C, U1.9 (6)
DATA5: RN1.8, T7.C, U1.11 (8)
DATA6: RN1.9, T8.C, U1.12 (9)
DATA7: RN1.10, T9.C, U1.13 (10)
FEED: RN1.5, T4.C, U1.17 (A0)
GND: C1.2, GND1.1, GND2.1, GND3.1, GND4.1, JP1.2, S1.1 (S), S1.2 (S1), T1.E, T2.E, T3.E, T4.E, T5.E, T6.E, T7.E, T8.E, T9.E, U1.3 (GND), U1.4 (GND), U1.23 (GND)
GND2: JP2.2, LED2.K (C), LED4.K (C), LED5.K (C), LED7.K (C), LED9.K (C)
unnamed: LED1.K (C), LED2.A
unnamed: LED3.K (C), LED5.A
unnamed: LED6.K (C), LED7.A
unnamed: LED8.K (C), LED9.A
unnamed: INV.1, U1.8 (5)
unnamed: TST.1, U1.6 (3)
unnamed: LED4.A, R5.1, R5A.1
unnamed: TX.1, U1.1 (TXO)
unnamed: 5BIT.1, U1.10 (7)
unnamed: S1.3, S1.4 (P1), U1.5 (2)
unnamed: LED1.A, R1.1, R1A.1
unnamed: LED3.A, R2.1, R2A.1
unnamed: LED6.A, R3.1, R3A.1
unnamed: LED8.A, R4.1, R4A.1
RAW: U1.24 (RAW)
VCC: C1.1, JP1.1, RN1.1, U1.21 (VCC)
VCC2: JP2.1, R1.2, R1A.2, R2.2, R2A.2, R3.2, R3A.2, R4.2, R4A.2, R5.2, R5A.2

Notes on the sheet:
16 MHz, 5 V
9 * photo-transistor Vishay BPW 17N
9 * LED Kingbright L2060-SRD
R1-R5 must be less than 2.4 mm thick. Standard through-hole size 0207 *may* fit; check manufacturer spec. Smaller through-hole size 0204 will definitely fit. SMD size 0603 or 0805 can be used alternatively.
Paper Tape Reader
juergen@e-basteln.de 12/2020
Populate either THT or SMD resistors. THT size 0204 or SMD 0603 or 0805.

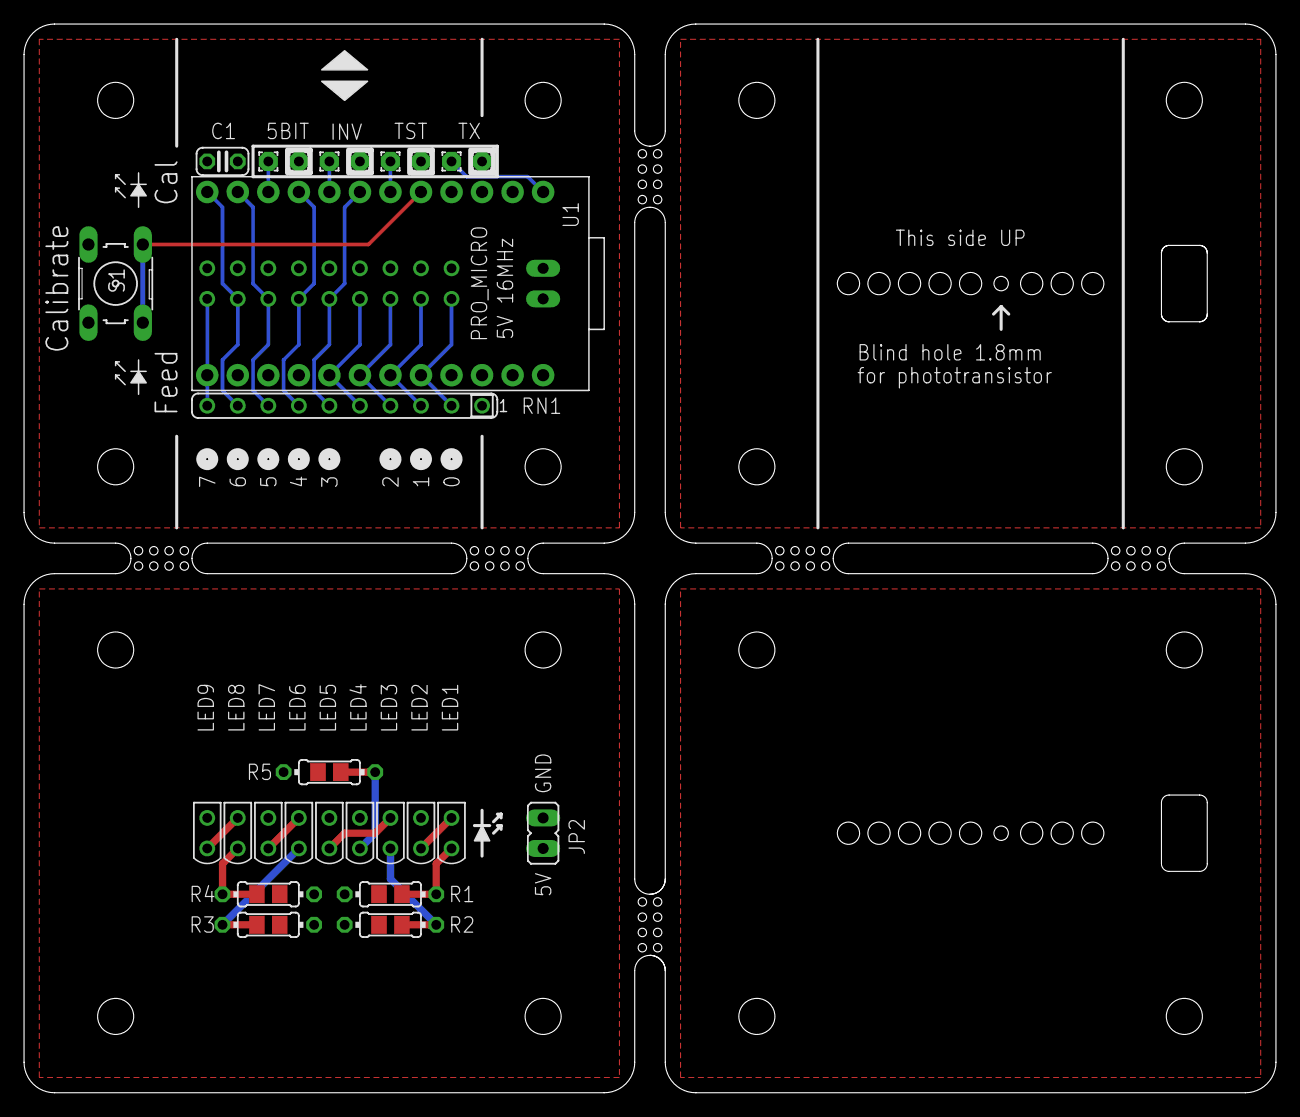
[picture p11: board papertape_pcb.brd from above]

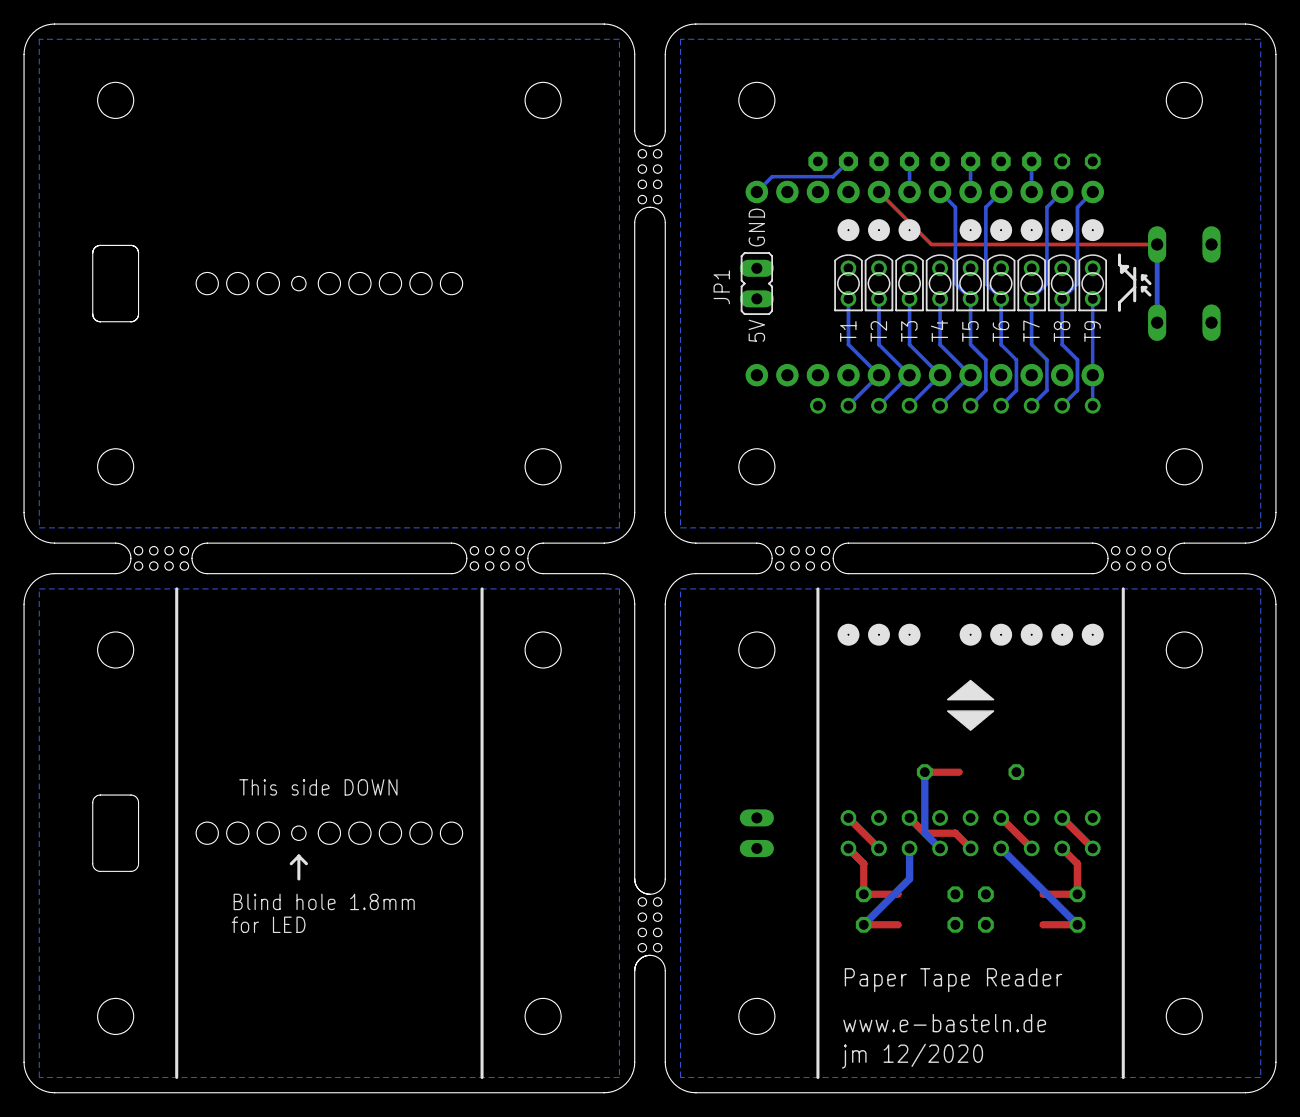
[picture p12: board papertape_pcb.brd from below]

Board: 2 copper layers, 104.1 x 88.9 mm, 42 parts (10 on the bottom side), 27 nets.

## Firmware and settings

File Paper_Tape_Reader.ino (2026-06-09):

/*
    Manual Paper Tape Reader with USB Serial (CDC) Interface
   
    For Sparkfun/Arduino Pro Micro (ATmega 32U4), 5V/16MHz version.
    Optical reader with LED/phototransistor pairs for each data bit and feed track;
    analog input of phototransistor signals for automatic threshold adaptation.
    ADC clock is increased to 1 MHz for approx. 50 kHz conversion rate with Arduino library.

    Jürgen Müller 22.12.2020
    juergen@e-basteln.de
    www.e-basteln.de


    *** LEDs

    FEED  flashes once for every valid feed hole detected during operation and calibration
    
    CAL   steady ON:        calibration mode is active
          flashing 1 Hz:    waiting for user to start calibration (press CAL button), or 10 s timeout
          flashing 10 Hz:   error during calibration process
          ON in read mode:  invalid brightness levels have been read (no clear high or low)


    *** Jumpers
     
    Three different tape widths can be set via jumpers. (Setting them is recommended 
    to avoid "CAL" indications from invalid detection levels at the tape edges, 
    and mask invalid bits from the output bytes.)

    Bits    Tape placement    Jumper settings
    8 bit   76543.210         5BIT=open TST=open
    7 bit   -6543.210         5BIT=set  TST=set
    5 bit   --432.10-         5BIT=set  TST=open

    Setting only the TST jumper will activate test mode, where the raw ADC readings
    from all 9 channels are printed on the output in an endless loop.


    *** Calibration

    ADC thresholds for distinguishing low vs. high bits are set in software,
    and can be calibrated by pushing the CAL button. Status output during calibration
    is provided via test messages (USB) and via the CAL LED.

    * Press CAL once: View current calibration.
      Current calibration values are printed via USB, 
      CAL LED blinks at 1 Hz.
    
    * Press CAL again within 10 seconds: Enter calibration mode.
      Prompts user to start feeding tape, 
      CAL LED on.

    * Feed tape, beginning within 10 seconds:
      Approx. 30 cm of sample tape are required.
      Ideally all data bits should be exercised in the sample, 
      but if no significant contrast is detected for a data channel, 
      averaged thresholds from the other channels will be used.
      CAL LED stays on, FEED LED begins to flash when valid feed holes are seen.

    * Calibration automatically ends when enough sample tape has been processed,
      or when one of the 10 second timeouts mentioned above is reached.
      Results and final status are printed via USB; 
      errors are also signalled by rapid flashing of the CAL LED for 1 second.
      CAL LED is then switched off. 
*/

#include <EEPROM.h>

// ===========================
// select whether TX is used for serial output (9600 Baud) or as a timing signal for debugging
// ===========================

#define TX_SERIAL 1

#if TX_SERIAL

#define SERIAL_WRITE(c) Serial1.write(c)
#define SERIAL_INIT(c) Serial1.begin(c)
#define TX_ON
#define TX_OFF

#else

#define TX_ON digitalWrite (OUT_TX, ON)
#define TX_OFF digitalWrite (OUT_TX, OFF)
#define SERIAL_WRITE(c)
#define SERIAL_INIT(c)

#endif

// ===========================
// Pinout definition.
// Note that these designate Arduino I/O numbers, not physical pins of the DIP package!
// ===========================

// analog inputs - 8 bit data plus transport track
#define AN_D0  A3
#define AN_D1  A2
#define AN_D2  A1
#define AN_D3  A6
#define AN_D4  A7
#define AN_D5  A8
#define AN_D6  A9
#define AN_D7  A10
#define AN_FEED  A0

// digital I/O and LEDs
#define LED_FEED LED_BUILTIN_TX   // TX LED (green) signals feed pulse
#define LED_CAL LED_BUILTIN_RX    // RX LED (yellow) signals calibration mode
#define IN_CAL  2                 // button to start calibration mode
#define IN_5BIT 7                 // jumper selects 5-bit mode (output >> 1) or 6-bit mode (together with TST jumper)
#define IN_INV  5                 // jumper selects inverted input levels (low intensity == logic 1)
#define IN_TST  3                 // jumper enables raw data output for testing
#define OUT_TX  1                 // general signaling & debugging - also serial TX

// I/O levels -- all digital inputs and outputs are active low 
#define ON 0
#define OFF 1

// ===========================
// global constants and variables
// ===========================

// calibration values per channel
struct calibRec {
  byte min;       // lowest value read
  byte max;       // highest value read
  byte mod;       // modulation depth
  byte low;       // values below this threshold are valid '0'
  byte high;      // values above this threshold are valid '1'
  byte mid;       // midpoint between min and max defines "best guess" at 0 or 1
  boolean est;    // this entry is interpolated from other channels
};

struct calibRec calibData [8];    // calibration records for 8 data channels
struct calibRec calibFeed;        // calibration data for Feed track

const unsigned addrFeed = 0;     // EEPROM address of calibFeed
const unsigned addrData = sizeof (calibRec);  // EEPROM address of calibData

byte inv = 0xFF;                  // inversion mask for inputs, toggled by INV jumper

// plausibility tests for acceptable signals during calibration
const byte minlevel = 100;        // minimum "max" value for acceptable signal level
const unsigned contrast = 80;     // maximum "min" value as percentage of "max" value for acceptable modulation

const long timeout = 10000;       // 10 s timeout at various calibration steps


// ===========================
// initialize 
// ===========================

void setup() 
{
  // Initialize digital I/O pins.
  pinMode (IN_CAL, INPUT_PULLUP);
  pinMode (IN_INV, INPUT_PULLUP);
  pinMode (IN_5BIT, INPUT_PULLUP);
  pinMode (IN_TST, INPUT_PULLUP);
  pinMode (OUT_TX, OUTPUT);
  pinMode (LED_FEED, OUTPUT);
  pinMode (LED_CAL, OUTPUT);

  digitalWrite (LED_FEED, OFF);  
  digitalWrite (LED_CAL, OFF);  
  TX_OFF;
  
  // Initialize USB serial comm.
  // Don't check for availability of the serial port; USB might be used for power supply only
  Serial.begin(9600);                 // baud rate is a dummy, not relevant for CDC

  // Initialize serial TX if enabled
  SERIAL_INIT(9600);

  // set ADC clock prescaler. 
  // 1 MHz gives stable results, 2 MHz gets noisy on some channels
  // ADCSRA = (ADCSRA&0xF80)|0x03;    // 1/8 (2 MHz ADC clock)
  ADCSRA = (ADCSRA&0xF80)|0x04;       // 1/16 (1 MHz ADC clock)

  // Read calibration data from EEPROM. 
  EEPROM.get (addrData, calibData);
  EEPROM.get (addrFeed, calibFeed);
}

// ===========================
// Calibration
// ===========================

// ---------------------------
// Print current calibration values for Feed track
// ---------------------------

void cal_print_feed ()
{
  Serial.println  ();
  Serial.println  ("\tFeed track calibration");
  Serial.println  ("\tBit\tMin\tMax\tMod\tLow\tHigh"); 
  Serial.print    ("\tFeed\t");
  Serial.print    (calibFeed.min);  Serial.print ("\t");
  Serial.print    (calibFeed.max);  Serial.print ("\t");
  Serial.print    (calibFeed.mod);  Serial.print ("%\t");
  Serial.print    (calibFeed.low);  Serial.print ("\t");
  Serial.print    (calibFeed.high); Serial.println ();
}

// ---------------------------
// Print current calibration values for Data tracks
// ---------------------------

void cal_print_data ()
{
  byte i;
  Serial.println ();    
  Serial.println ("\tData calibration");
  Serial.println ("\tBit\tMin\tMax\tMod\tLow\tHigh"); 
  for (i=0; i<8; i++) {
    Serial.print ("\t");
    Serial.print (i);                  Serial.print ("\t");
    Serial.print (calibData[i].min);   Serial.print ("\t");
    Serial.print (calibData[i].max);   Serial.print ("\t");
    Serial.print (calibData[i].mod);   Serial.print ("%\t");
    Serial.print (calibData[i].low);   Serial.print ("\t");
    Serial.print (calibData[i].high);  Serial.print ("\t");
    if (calibData[i].est) Serial.print ("interpolated"); 
    Serial.println ();
  }
}

// ---------------------------
// Wait for button release and new button press.
// Blink LED at 1 Hz while waiting.
// Returns true if successful (no timeout)
// ---------------------------

boolean cal_button ()
{
  long t;
  long endtime = millis() + timeout;
  
  while ((digitalRead (IN_CAL) == ON) && ((t = millis()) < endtime))  // wait for button release or timeout
    digitalWrite (LED_CAL, ((endtime-t)/500) % 2);                    // blink LED @ 1Hz
  delay (100);                                                        // debounce time
  while ((digitalRead (IN_CAL) == OFF) && ((t = millis()) < endtime)) // wait for button press or timeout
    digitalWrite (LED_CAL, ((endtime-t)/500) % 2);                    // blink LED @ 1 Hz
  return millis() < endtime;                                          // no button pressed, timed out
}

void cal_error (char* msg)
{
  Serial.println ();
  Serial.print ("--- ");
  Serial.println (msg);
  for (int i=0; i<10; i++) {
    digitalWrite (LED_CAL, ON); delay (50);
    digitalWrite (LED_CAL, OFF); delay (50);    
  }
}

// ---------------------------
// Feed sensor calibration.
// Waits until valid modlation amplitude is seen, then follows 20 feed hole level changes.
// Returns true if successful (no timeout)
// ---------------------------

boolean cal_read_feed ()
{
  byte b;
  unsigned i;
  long endtime = millis() + timeout;
  
  // wait until minimum modulation depth established, or 10s timeout 
  // abort after timeout in feed calibration 
  calibFeed.max = 0;
  calibFeed.min = 255;  
  while (((calibFeed.max < minlevel) || (contrast*calibFeed.max < 100*calibFeed.min)) && (millis() < endtime)) {
    b = (analogRead (AN_FEED)>>2)^inv;
    if (b > calibFeed.max) calibFeed.max = b;
    else if (b < calibFeed.min) calibFeed.min = b;
  }
  // initial thresholds
  calibFeed.low = (2*calibFeed.min + calibFeed.max)/3;
  calibFeed.high = (calibFeed.min + 2*calibFeed.max)/3;

  // wait for 20 maxima and minima, or new 10s timeout
  if (millis() < endtime) {
    endtime = millis() + timeout;
    for (i=0; i<20; i++) {
      
      // wait for feed hole to pass
      while (( (b = (analogRead (AN_FEED)>>2)^inv) > calibFeed.low) && (millis() < endtime)) {
        if (b > calibFeed.max) calibFeed.max = b;
        else if (b < calibFeed.min) calibFeed.min = b;      
      }
      digitalWrite (LED_FEED, OFF);
      
      // wait for new feed hole to appear
      while (( (b = (analogRead (AN_FEED)>>2)^inv) < calibFeed.high) && (millis() < endtime)) {
        if (b > calibFeed.max) calibFeed.max = b;
        else if (b < calibFeed.min) calibFeed.min = b;      
      }
      digitalWrite (LED_FEED, ON);
      
      // update thresholds
      calibFeed.low = (2*calibFeed.min + calibFeed.max)/3;
      calibFeed.high = (calibFeed.min + 2*calibFeed.max)/3;
    }

    // calculate secondary cal parameters and print feed calibration
    calibFeed.mid = (calibFeed.min + calibFeed.max)/2;
    calibFeed.mod = 100 - (100*calibFeed.min)/calibFeed.max;
  }
  return (millis() < endtime);  
}

// ---------------------------
// Data sensor calibration.
// Reads 50 data bytes (triggered by feed track), sets min and max values in calibData record.
// Returns true if successful (no timeout).
// ---------------------------

boolean cal_read_data ()
{
  byte b;
  byte ad[8];
  unsigned i, j;
  long endtime;

  for (i=0; i<8; i++) {
    calibData[i].max = 0;
    calibData[i].min = 255;  
  }  
  
  for (j=0; j<50; j++) {

    // wait for feed hole to go and come, with 10s timeout
    endtime = millis() + timeout;
    while ((((analogRead (AN_FEED) >> 2)^inv) > calibFeed.low) && (millis() < endtime));  // wait for prior feed hole to pass
    digitalWrite (LED_FEED, OFF);
    while ((((analogRead (AN_FEED) >> 2)^inv) < calibFeed.high) && (millis() < endtime)); // wait for new feed hole
    digitalWrite (LED_FEED, ON);
    if (millis() >= endtime) break;

    // read all 8 data bits (quickly)
    ad[0] = analogRead (AN_D0) >> 2;
    ad[1] = analogRead (AN_D1) >> 2;
    ad[2] = analogRead (AN_D2) >> 2;
    ad[3] = analogRead (AN_D3) >> 2;
    ad[4] = analogRead (AN_D4) >> 2;
    ad[5] = analogRead (AN_D5) >> 2;
    ad[6] = analogRead (AN_D6) >> 2;
    ad[7] = analogRead (AN_D7) >> 2;  

    // process data
    for (i=0; i<8; i++) {
      b = ad[i]^inv;
      if (b > calibData[i].max) calibData[i].max = b;
      else if (b < calibData[i].min) calibData[i].min = b;
    }
  }
  return millis() < endtime;
}

// ---------------------------
// Data sensor post-processing.
// Identifies channels with valid modulation, calculates interpolated min and max values for invalid channels.
// Calculates secondary modulation data (thresholds, modulation depth) for all channels.
// Returns true if >= 4 channels with valid modulation were found.
// ---------------------------

boolean cal_process_data ()
{
  unsigned sum_max, sum_min, n_val, i;

  // identify data bits which meet minimum modulation criterion
  sum_max = 0; sum_min = 0; n_val = 0;
  for (i=0; i<8; i++) {
    if ((calibData[i].max > minlevel) && (contrast*calibData[i].max > 100*calibData[i].min)) {   // valid signal and modulation depth
      calibData[i].est = false;
      sum_max += calibData[i].max;
      sum_min += calibData[i].min;
      n_val++;
    } else {
      calibData[i].est = true;      
    }
  }

  // calculate interpolated values for non-modulated bits, 
  // plus secondary calibration values
  if (n_val > 0) {
    sum_max = sum_max/n_val;
    sum_min = sum_min/n_val;
  } else {
    sum_max = 1;  // avoid div by 0 below
    sum_min = 0;
  }
  for (i=0; i<8; i++) {
    if (calibData[i].est) {
      calibData[i].max = sum_max;
      calibData[i].min = sum_min;
    }
    calibData[i].low = (2*calibData[i].min + calibData[i].max)/3;     // 1/3 above min
    calibData[i].high = (calibData[i].min + 2*calibData[i].max)/3;    // 1/3 below max
    calibData[i].mid = (calibData[i].min + calibData[i].max)/2;       // halfway between min and max
    calibData[i].mod = 100 - (100*calibData[i].min)/calibData[i].max;
  }
  return (n_val >= 4);  
}

// ---------------------------
// Calibration main routine.
// Control flow, prints status messages via USB serial interface.
// ---------------------------

void calibrate ()
{
  boolean valid;
    
  // print current calibration status
  Serial.println ();
  Serial.println ("Current calibration:");
  cal_print_feed ();
  cal_print_data ();

  // wait for another button press
  Serial.println ();
  Serial.println ("*** Insert tape and press CAL button again to start new calibration,");
  Serial.println ("    or wait for 10 second timeout.");

  if (!cal_button ()) {
    Serial.println ();
    Serial.println ("--- Timeout - using current calibration");
    digitalWrite (LED_CAL, OFF);
    return;    
  }
  
  // feed sensor calibration
  digitalWrite (LED_CAL, ON);
  Serial.println ();
  Serial.println ("*** Calibrating feed sensor. Please feed tape...");
  
  if (cal_read_feed ()) {
    cal_print_feed ();
  } else {
    cal_error ("Timeout waiting for feed holes - using prior calibration");
    EEPROM.get (addrFeed, calibFeed);   
    return;
  }
  
  // data sensor calibration: read 50 data bytes
  Serial.println ();
  Serial.println ("*** Calibrating data sensors. Please keep feeding...");

  if (cal_read_data ()) {
    valid = cal_process_data ();
    cal_print_data ();
  } else{
    cal_error ("Timeout waiting for data - using prior calibration");
    EEPROM.get (addrData, calibData);   
    EEPROM.get (addrFeed, calibFeed);   
    return;
  }

  // check validity, store new or recover old calibration
  Serial.println ();
  if (valid) {         // need at least three data bits with actual modulation
    Serial.println ("--- Calibration complete and stored");
    EEPROM.put (addrData, calibData);
    EEPROM.put (addrFeed, calibFeed);    
  } else {
    cal_error ("Less than 4 valid data channels - using prior calibration");
    EEPROM.get (addrData, calibData);    
    EEPROM.get (addrFeed, calibFeed);    
  }
  Serial.println ();
  digitalWrite (LED_CAL, OFF);
}

// ===========================
// main loop
// ===========================

// ---------------------------
// Test mode (selected by TST jumper):
// Display all ADC values
// ---------------------------

void main_testmode ()
{
  byte ad[9];
  byte i;

  // capture all 9 inputs
  TX_ON;
  ad[0] = analogRead (AN_D0) >> 2;
  ad[1] = analogRead (AN_D1) >> 2;
  ad[2] = analogRead (AN_D2) >> 2;
  ad[3] = analogRead (AN_D3) >> 2;
  ad[4] = analogRead (AN_D4) >> 2;
  ad[5] = analogRead (AN_D5) >> 2;
  ad[6] = analogRead (AN_D6) >> 2;
  ad[7] = analogRead (AN_D7) >> 2;
  ad[8] = analogRead (AN_FEED) >> 2;
  TX_OFF;

  // display all ADC levels, with inversion as selected by INV jumper
  for (i=0; i<9; i++) {
    Serial.print (ad[i]^inv); Serial.print ("\t");
  }
  Serial.println ();
}

// ---------------------------
// Standard operation:
// Read byte when triggered by feed track, transmit via USB serial (and RS-232 TX if enabled).
// Poll CAL button and call calibration routine when required.
// ---------------------------

void main_runmode ()
{
  byte ad[8];
  byte a, b;
  short int i;
  byte valid;
  
  // look for next feed hole.
  TX_ON;                                                    // ready to look for transport hole
  while (((analogRead (AN_FEED)>>2)^inv) > calibFeed.low)   // wait for prior feed hole to pass
    if (digitalRead (IN_CAL) == ON) calibrate ();           // calibration button pressed?
  digitalWrite (LED_FEED, OFF);
  
  while (((analogRead (AN_FEED)>>2)^inv) < calibFeed.high)  // wait for new feed hole
    if (digitalRead (IN_CAL) == ON) calibrate ();           // calibration button pressed?
  digitalWrite (LED_FEED, ON);
  TX_OFF;                                                   // found new transport hole

  // read all 8 data bits (quickly)
  TX_ON;                            // begin conversion
  ad[0] = analogRead (AN_D0) >> 2;
  ad[1] = analogRead (AN_D1) >> 2;
  ad[2] = analogRead (AN_D2) >> 2;
  ad[3] = analogRead (AN_D3) >> 2;
  ad[4] = analogRead (AN_D4) >> 2;
  ad[5] = analogRead (AN_D5) >> 2;
  ad[6] = analogRead (AN_D6) >> 2;
  ad[7] = analogRead (AN_D7) >> 2;
  TX_OFF;                           // end conversion

  // set valid mask to ignore bits at the edges of the tape
  if (digitalRead (IN_5BIT) == OFF) valid = 0xFF;       // 5-bit jumper open: 8-bit mode
  else if (digitalRead (IN_TST) == OFF) valid = 0x3E;   // 5-bit jumper set, TST jumper open: 5-bit mode
  else valid <= 0x7F;                                   // 5-bit jumper and TST jumper set: 7-bit mode
  
  // check for valid data, convert, set quality LED
  digitalWrite (LED_CAL, OFF);
  for (i=7; i>=0; i--) {
    b = b<<1;
    a = ad[i]^inv;
    if (a > calibData[i].mid) b |= 0x01;    // '1' bit value
    if ((a > calibData[i].low) && (a < calibData[i].high) && (valid & 0x80)) digitalWrite (LED_CAL, ON);    // signal an invalid state
    valid = valid << 1;
  }

  // output the byte to Serial (USB), and to Serial1 (TX) if enabled
  if (digitalRead (IN_5BIT) == OFF) {         // 5-bit jumper open: 8-bit mode
    Serial.write(b);
    SERIAL_WRITE(b);               
  } else if (digitalRead (IN_TST) == OFF){    // 5-bit jumper set, TST jumper open: 5-bit mode
    Serial.write((b>>1) & 0x1F);
    SERIAL_WRITE((b>>1) & 0x1F);   
  } else {                                    // 5-bit jumper and TST jumper set: 7-bit mode
    Serial.write(b & 0x7F);
    SERIAL_WRITE(b & 0x7F);       
  }
}

// ---------------------------
// Main loop:
// Poll INV and TST jumpers, call appropriate operating routine
// ---------------------------

void loop() 
{
  // Raw ADC input values are high for dark phototransistors;
  // Values will be inverted in normal operation (hole -> light -> high inverted value -> logical 1).
  // If INV jumper is set, don't invert.
  if (digitalRead (IN_INV) == ON) inv = 0x00; 
  else inv = 0xFF;

  if ((digitalRead (IN_TST) == ON) and (digitalRead (IN_5BIT) == OFF)) {
    // if TST jumper is set and 5BIT open, activate test mode: 
    // display all ADC values continuously via USB
    main_testmode ();
  } else { 
    // otherwise, read one byte triggered by feed track and write to USB
    main_runmode ();
  }
}

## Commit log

2026-06-09 Add paper tape reader project with KiCad PCBs and documentation.
    Eagle designs converted to KiCad with pre-drill holes; main and spacer boards combined in a panel layout. Includes firmware, Gerbers, BOM, and build documentation sourced from e-basteln.
    [Paper_Tape_Template.xlsx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]
2026-06-09 Add CSV bill of materials with manufacturer part numbers.
    Derived from papertape_bom.pdf so builders can source parts by MPN instead of Reichelt catalog numbers.
    [papertape_bom.csv]
2026-06-09 Add PCBWay shared project link and badge to README.
    Makes it easier to order PCBs directly from the published PCBWay project.
2026-06-11 Update README with KiCad conversion details
    Converted Eagle designs to KiCad and merged spacer boards into main PCB file.
2026-06-11 Enhance README with detailed project information
    Updated README to include additional details about the paper tape reader, including design files and assembly instructions.
2026-06-11 Revise README with enhanced project details
    Updated README to include additional details about PCB specifications, design approach, and building instructions.
2026-06-11 Fixed hole sizes.
    [papertape_panel-B_Cu.gbr, papertape_panel-B_Mask.gbr, papertape_panel-B_Silkscreen.gbr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]
2026-06-11 Updated kicad files.
    [papertape_panel.kicad_pcb, papertape_pcb.kicad_pcb]
2026-06-11 Enhance README with detailed assembly and design info
    Updated README to include additional details on PCB specifications, assembly instructions, and design files.
2026-06-26 Revise README for clarity and additional information
    Updated README to include additional details about PCB specifications, assembly instructions, and design files.
2026-06-26 Document PCBWay part list and panel ordering details in README.
    Add the PCBWay community BOM CSV and note that the shared project includes all parts needed to build the reader.
    [papertape_bom_PCBWay Community.csv]
2026-06-27 Add feed-track blind-hole drilling depth guidance to README.
    Document PCB tolerance, LED protrusion, recommended start depth, and maximum drill depth for the feed aperture.
2026-06-27 Add feed-track drilling photo to README.
    Include papertape_panel-readme.jpg under the blind-hole drilling instructions.
2026-06-27 Update panel gerbers with silkscreen drilling guidance.
    Regenerate papertape_panel exports after adding README drilling notes to the panel silkscreen.
    [papertape_panel-B_Cu.gbr, papertape_panel-B_Mask.gbr, papertape_panel-B_Paste.gbr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]
2026-06-27 Add panel silkscreen notes for feed-track blind-hole drilling.
    Mark the correct drill side and point builders to README drilling instructions.
    [papertape_panel.kicad_pcb]
